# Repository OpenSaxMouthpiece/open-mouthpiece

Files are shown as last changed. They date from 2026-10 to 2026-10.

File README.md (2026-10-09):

<p>
  <picture>
    <source media="(prefers-color-scheme: dark)" srcset="docs/images/logo-dark.svg">
    
  </picture>
</p>

# Open Mouthpiece

**Design your own saxophone mouthpiece in the browser, then 3D-print it.**
Try it: **https://opensaxmouthpiece.org** · [User guide](docs/GUIDE.md)

> **This project is AI-generated.** The code, the mouthpiece generator, the presets and the
> documentation were written by Claude, Anthropic's AI model. A saxophonist directed it and prints
> and plays the results; see [How this was made](#how-this-was-made).

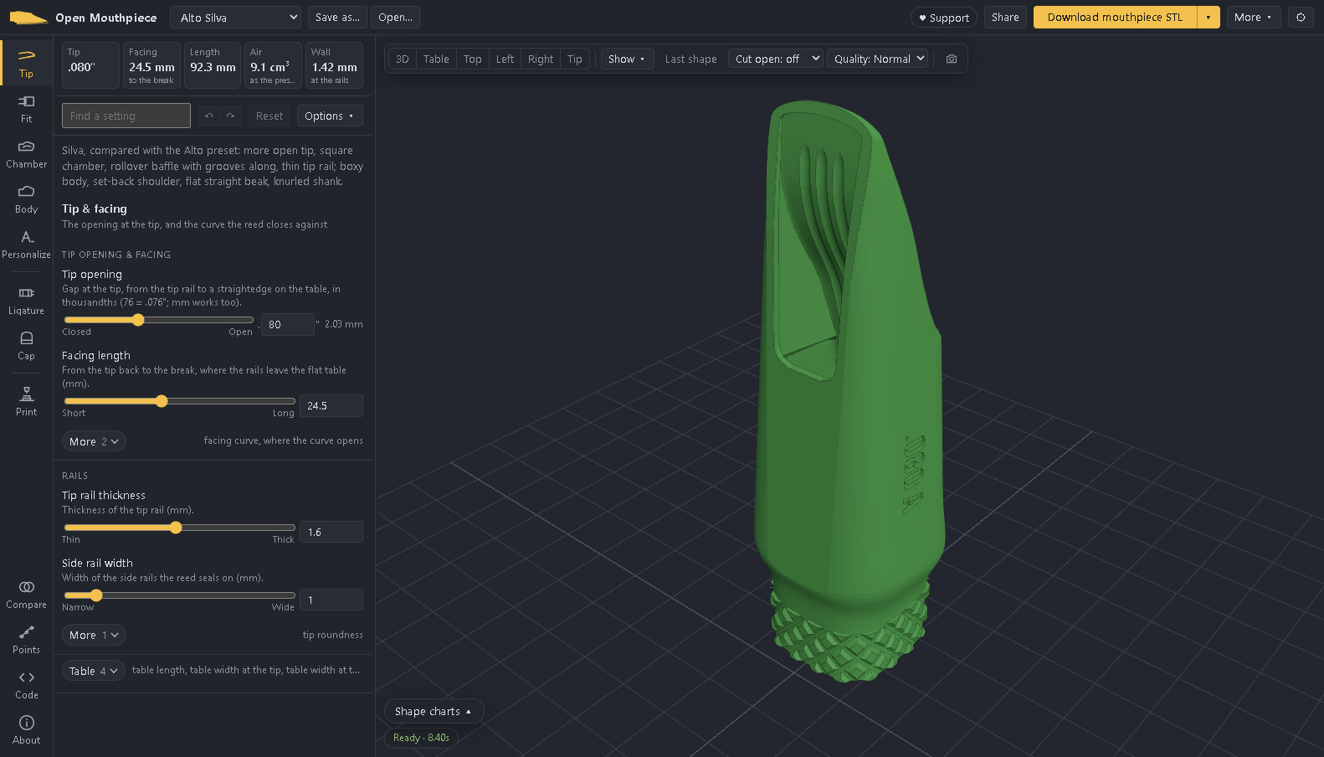
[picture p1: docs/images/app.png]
The app: the section buttons down the left, the readouts and the tip and facing settings, and a variant with lettering and a knurled shank in the 3D view


Change real design parameters (tip opening, facing, chamber, baffle, window, body and beak) and
download a printable STL. Everything runs in your browser: no account, nothing to install, and
nothing is saved on a server.

## What it does

- **Start from a preset**: soprano, alto, tenor or baritone, each with three variants (Flamma,
  Silva, Unda), plus a C-melody.
- **Shape it in sax terms**: tip opening in thousandths, facing length and curve (drag it, or pick
  one), chamber, baffle, window, body and beak. Every slider says what each end does.
- **Drag the shape itself**: the shape card over the view shows the facing, the outside and the
  inside from the side and in a slice across; **Edit shape** lets you pull their lines.
- **See the numbers**: tip, facing, length, inside air volume (and where that sits on the cork) and
  thinnest wall, and where feeler gauges stop along the facing.
- **Fit your horn**: set your neck cork's diameter and how tight it should be; print a small test
  ring first to check.
- **Make a matching ligature and cap**: a ring ligature and a cap built from the mouthpiece's own
  shape.
- **Compare A/B** with another design, with the original, or with an STL of a mouthpiece you have.
- **Personalize it**: text and pictures on the top, sides and shank, and rings, flutes, a spiral or
  knurling around the shank.
- **Keep and share**: save in your browser, download a .scad (it opens in OpenSCAD), the STL or a
  whole print kit, or send a link.
- Works on phones and tablets too.

The generator keeps every realistic combination printable: walls, the socket and the window are
limited so that no setting breaks the model.

| Shape charts | Compare A/B |
|---|---|
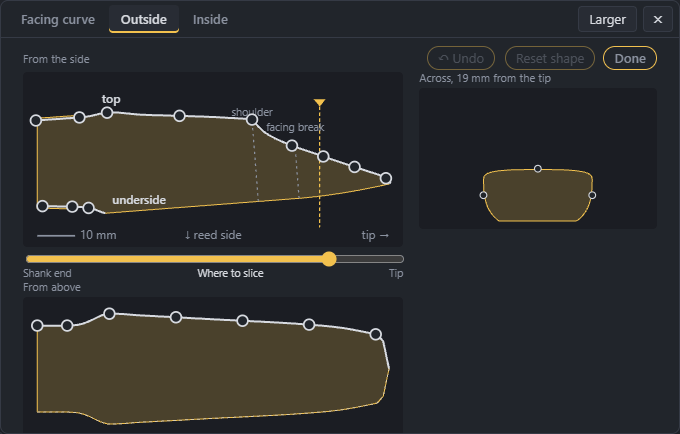
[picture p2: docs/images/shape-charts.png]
The outside chart in Edit shape: the side view with dots on the top and underside, a slice across it, and the view from above
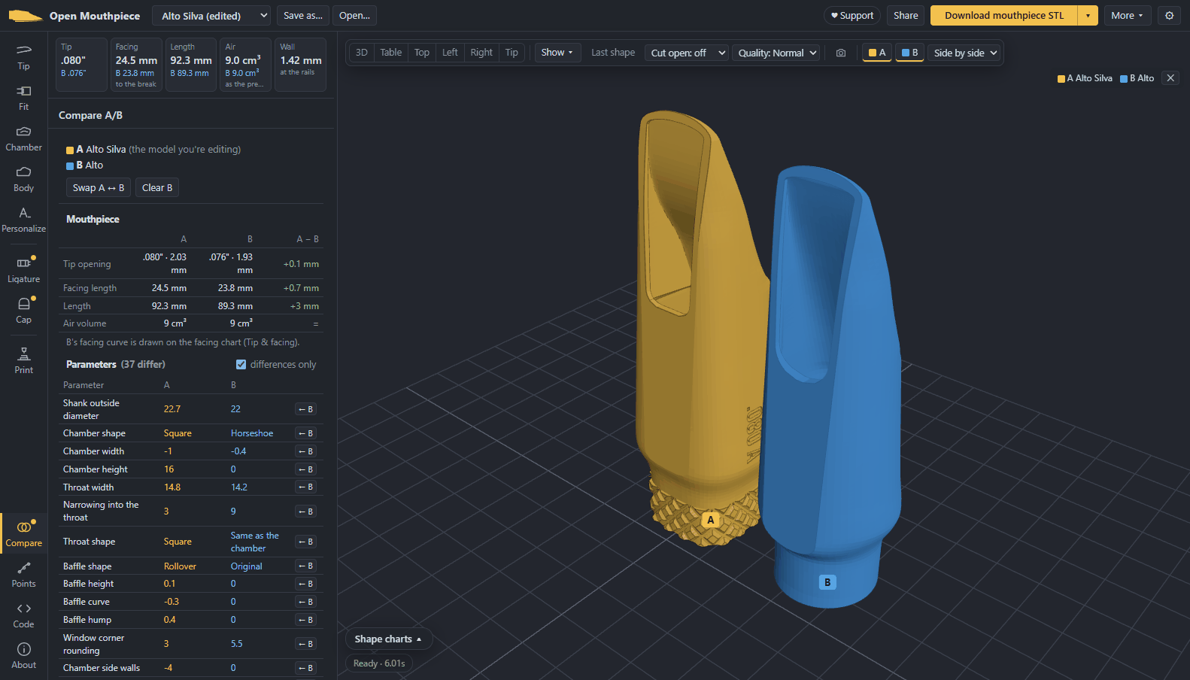
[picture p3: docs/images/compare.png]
A variant and the alto preset side by side, with the settings that differ
|  |  |
| **Ligature and cap** | **Phone** |
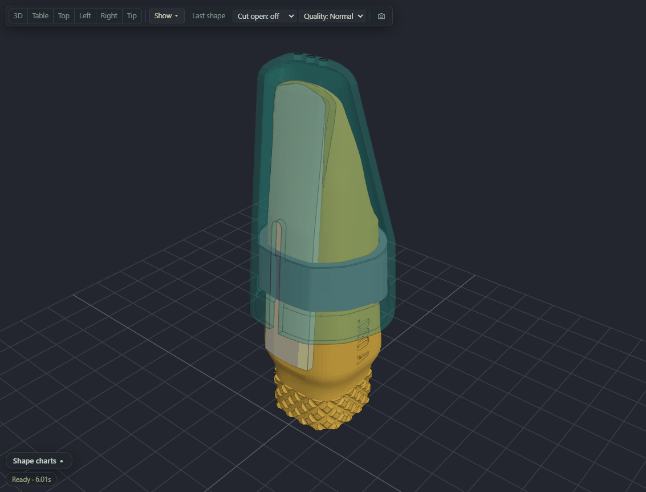
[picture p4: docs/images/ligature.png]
A mouthpiece with its reed, a printed ring ligature and a see-through cap
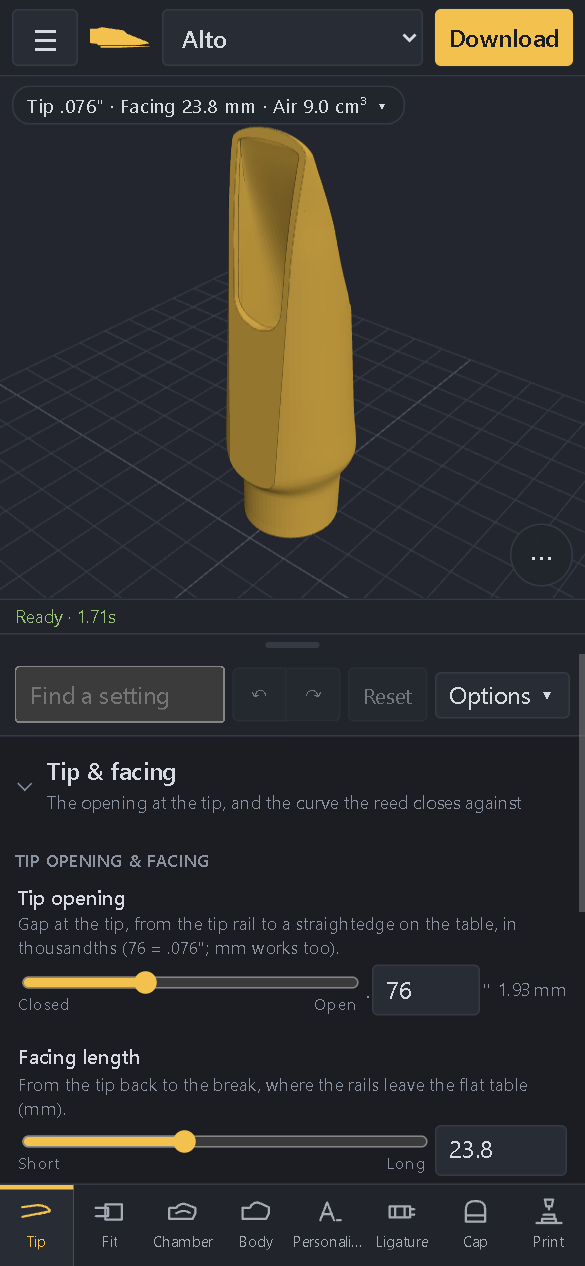
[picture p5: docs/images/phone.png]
The app on a phone: the view, the settings and the section bar along the bottom
|  |  |

## Status

Early but usable. The alto, tenor and baritone presets have been printed and played; the soprano,
the variants, the C-melody, the ligature and the cap haven't been printed yet.
[docs/PRINTING.md](docs/PRINTING.md) walks through printing, fitting and play-testing.
Feedback and prints are welcome (open an issue).

## Run it locally

The app needs only Node.js (OpenSCAD runs in the browser). The test scripts (`npm run check`,
`npm run sweep`) also need a recent OpenSCAD nightly (for the Manifold backend): set `OPENSCAD`
to its command-line program, or have `openscad` on the PATH.

```
npm install
npm run dev            # the app (OpenSCAD runs in the browser)
```

- **User guide**, from a first mouthpiece to every tool in the app: [docs/GUIDE.md](docs/GUIDE.md)
- The parts of a mouthpiece, and which settings change each: [docs/GLOSSARY.md](docs/GLOSSARY.md)
- Every setting, with pictures of what it changes: [docs/PARAMETERS.md](docs/PARAMETERS.md)
- Printing and play-testing: [docs/PRINTING.md](docs/PRINTING.md)
- Putting the app online: [docs/HOSTING.md](docs/HOSTING.md)
- Working on the code: [CONTRIBUTING.md](CONTRIBUTING.md)

The live site collects anonymous usage and error reports to improve the app: which designs and
settings get used, what gets printed (its numbers) and what fails. Never lettering, pictures or file
names, no cookies, no IP addresses, nothing that links one visit to the next; ⚙ "Share anonymous
usage" turns it off.

Open Mouthpiece is free, with no ads. If it made you a mouthpiece you like, you can
[support it on Ko-fi](https://ko-fi.com/opensaxmouthpiece).

## How this was made

Open Mouthpiece is AI-generated ("vibe coded"): the OpenSCAD generator, this web app, the
presets' measurements and the documentation were written by Claude, Anthropic's AI model, in
conversation with a saxophonist who set the direction, made the design calls, and prints and plays
the results. Read the code, and the numbers it gives you, with that in mind. The geometry is checked by automated
tests: every preset must come out as one closed, printable solid that matches its stored
reference, and a sweep tries over a thousand extreme and random settings to make sure they still
print. Printed alto, tenor and baritone pieces have been play-tested; reports from your own prints
are welcome.

## Credits

- **Anatomy and design parameters** follow M. Ozdemir et al., *Acta Acustica* 5, 46 (2021),
  open access under CC BY 4.0:
  https://acta-acustica.edpsciences.org/articles/aacus/abs/2021/01/aacus210019/aacus210019.html
- **Preset dimensions** were measured from Windy City Woodwinds' mouthpiece models on Thingiverse
  (CC BY-NC-SA): the "64" soprano (https://www.thingiverse.com/thing:6645219), "64" alto
  (https://www.thingiverse.com/thing:6645230), "64" tenor (https://www.thingiverse.com/thing:6645238) and
  "64" bari (https://www.thingiverse.com/thing:6645244). Their outlines were measured as coarse
  tables (a few to about 15 points per curve, smoothed by hand; the soprano's more finely) and
  rebuilt in this generator; no mesh from those models is included here. The ligature follows the
  idea of their printed friction-fit ligature. The site credits them too.
- **Fonts** in `scad/lib/fonts/` are under the SIL Open Font License (licence files alongside).
- **OpenSCAD** (GPL-2.0-or-later, source at https://github.com/openscad/openscad) does the
  geometry; the app runs its official WebAssembly build.

## License

Copyright (C) 2026 OpenSaxMouthpiece contributors.

This program is free software: you can redistribute it and/or modify it under the terms of the
GNU General Public License as published by the Free Software Foundation, either version 3 of the
License, or (at your option) any later version. See [LICENSE](LICENSE).

- **Your designs are yours.** The license covers this code, not the mouthpieces you design with it:
  the STLs you export and the objects you print from them are yours to use, share or sell. (A
  full .scad download contains the generator's code, so sharing that file shares GPL code.)
- **Name:** "Open Mouthpiece" and opensaxmouthpiece.org are not licensed under the GPL; a fork
  is welcome, under its own name.
- Third-party parts keep their own licenses (see Credits).

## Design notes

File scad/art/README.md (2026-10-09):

# Pictures for `top_image`

SVG drawings the generator can engrave (or raise) on the mouthpiece, the ligature or the cap. Pick one in the
app (Personalize → Picture on top), or upload your own there.

Examples (original drawings, same license as the project):

| File | Suggested `top_image_width` |
|---|---|
| `saxophone.svg` | 16 mm or more |
| `happy_face.svg` | 10 mm or more |
| `sample_note.svg` | 10 mm or more |
| `treble_clef.svg` | 8 mm or more |
| `beamed_notes.svg` | 10 mm or more |
| `star.svg` | 8 mm or more |
| `heart.svg` | 8 mm or more |
| `flame.svg` | 10 mm or more |
| `skull.svg` | 10 mm or more |
| `cat.svg` | 10 mm or more |
| `bird.svg` | 12 mm or more |
| `wave.svg` | 12 mm or more |
| `lightning.svg` | 8 mm or more |
| `ash_leaf.svg` | 10 mm or more |
| `birch_leaf.svg` | 8 mm or more |
| `cedar_tree.svg` | 8 mm or more |
| `element_fire.svg`, `element_leaf.svg`, `element_water.svg` (a set) | 10 mm or more |

## Making your own

- **Use filled shapes.** OpenSCAD reads fills; outlines (strokes) come out filled in or broken.
  In Inkscape: select all, Path → Stroke to Path.
- **Holes go inside the shape's own path** (a subpath with `fill-rule="evenodd"`, or drawn the
  opposite way round). A white shape drawn on top does nothing: colours are ignored.
- **Keep lines printable:** about 0.5 mm or wider at the width you engrave it (a line that is 3% of
  the drawing's width is 0.5 mm at 16 mm).
- Photos and PNGs need tracing to an outline first (Inkscape: Path → Trace Bitmap).
- Only use logos and artwork you have the right to use.

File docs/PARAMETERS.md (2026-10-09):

# Parameters

Every setting of the generator, as OpenSCAD's Customizer shows them. The app shows each one in a
section of its settings panel (the main ones first, the rest under the section's More), under
friendlier names; the name in brackets is the one in the `.scad` file. Lengths are in mm, angles in degrees.

Each picture is the alto preset at two values of one setting, the rest unchanged, seen where the
setting acts (a section when it acts inside):

- **gray**: in both
- **blue**: added going from the first value to the second
- **orange**: taken away going from the first value to the second

This page is made by `node scripts/param_docs.mjs` from `scad/lib/mouthpiece_base.scad`.

Sections: [Shank](#shank) · [Chamber](#chamber) · [Baffle](#baffle) · [Window](#window) · [Table](#table) · [Facing](#facing) · [Exterior](#exterior) · [Lettering](#lettering) · [Profile overrides](#profile-overrides) · [Manufacturing](#manufacturing) · [Ligature](#ligature) · [Cap](#cap) · [Output](#output)

## Shank

### Neck cork diameter (`neck_cork_diameter`)

Your neck cork's diameter (mm), measured with calipers.

Range: 10 to 27, step 0.05.

Presets: Alto `16.2` · Tenor `17.2` · Bari `18.0` · Soprano `13.8`.

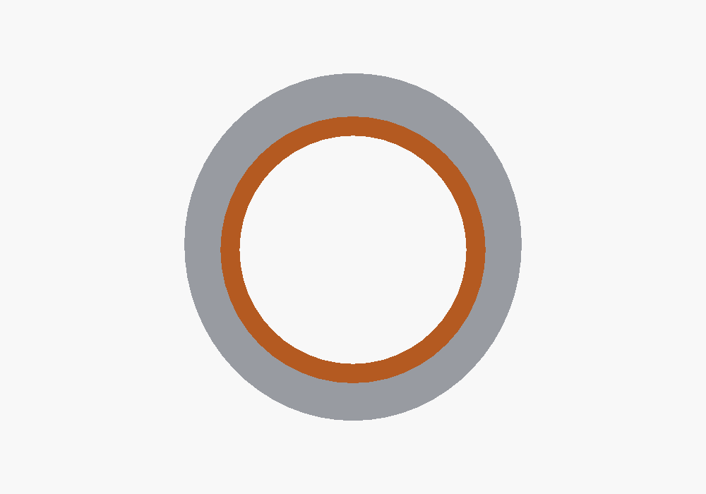
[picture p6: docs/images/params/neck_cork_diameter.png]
neck_cork_diameter: 15 → 17.5


*15 → 17.5*

### Cork squeeze (`shank_clearance`)

How much smaller than your cork the socket is (mm): bigger = tighter. Try 0.1-0.3.

Range: 0 to 0.6, step 0.01.

Presets: Alto `0.2` · Tenor `0.2` · Bari `0.2` · Soprano `0.2`.

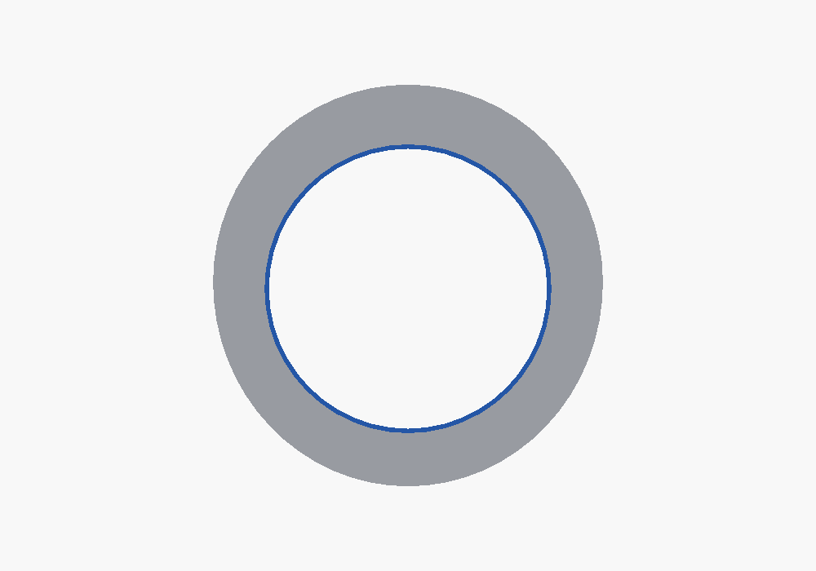
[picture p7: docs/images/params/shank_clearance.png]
shank_clearance: 0 → 0.5


*0 → 0.5*

### Lead-in at the opening (`shank_bevel`)

How much wider the socket's mouth is, per side (mm), to ease it onto the cork.

Range: 0 to 3, step 0.1.

Presets: Alto `1.0` · Tenor `1.0` · Bari `1.0` · Soprano `1.0`.

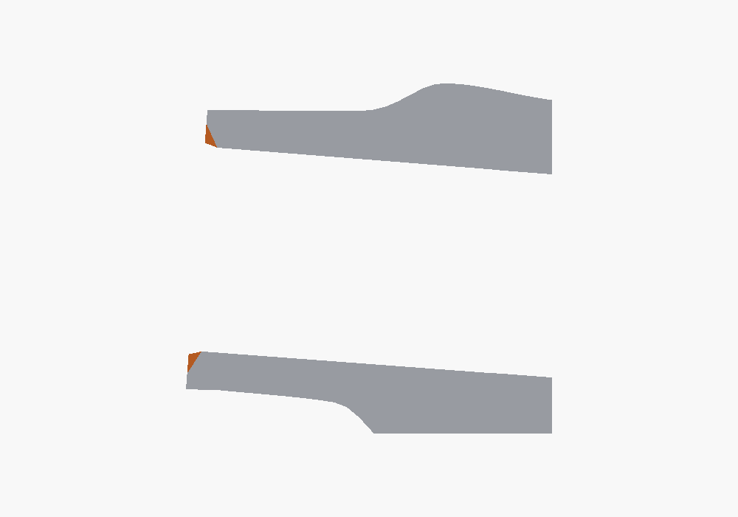
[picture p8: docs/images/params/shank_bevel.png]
shank_bevel: 0.3 → 1.8


*0.3 → 1.8*

### Lead-in length (`shank_bevel_depth`)

How far in the socket's lead-in goes (mm).

Range: 0.2 to 20, step 0.1.

Presets: Alto `1.0` · Tenor `1.0` · Bari `1.0` · Soprano `1.0`.

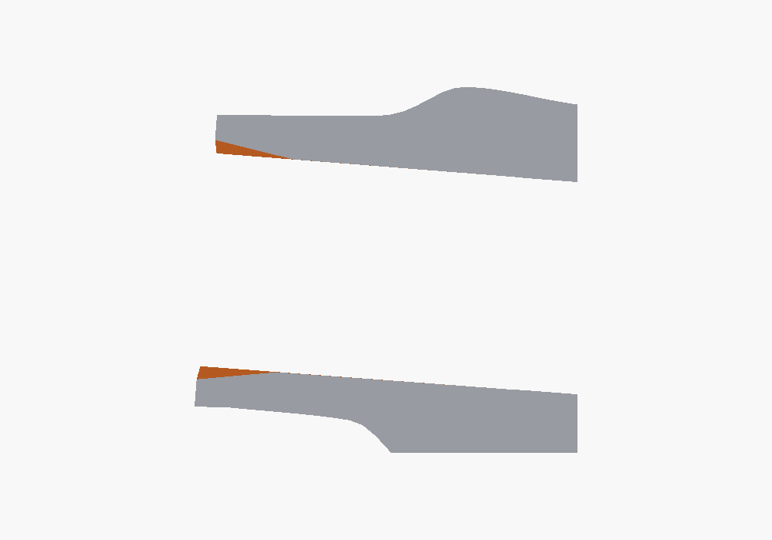
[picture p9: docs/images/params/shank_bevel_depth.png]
shank_bevel_depth: 0.2 → 6


*0.2 → 6*

### How far the cork goes in (`shank_depth`)

How far the cork goes in (mm). Other settings give way to keep it.

Range: 10 to 70, step 0.5.

Presets: Alto `22.0` · Tenor `26.0` · Bari `30.0` · Soprano `25.5`.

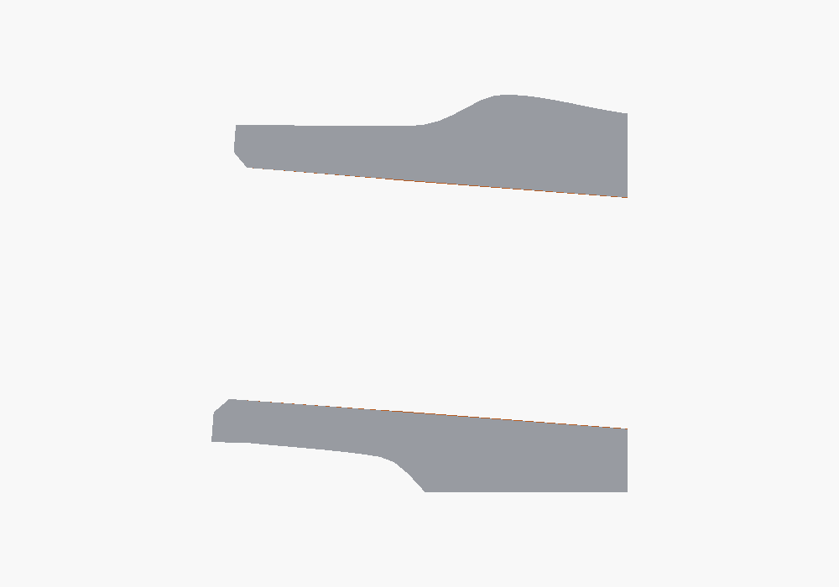
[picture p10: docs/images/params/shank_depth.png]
shank_depth: 10 → 37


*10 → 37*

### Bore (behind the cork) (`bore_diameter`)

Diameter of the tube behind the socket (mm), about your neck tip's inside diameter.

Range: 8 to 24, step 0.1.

Presets: Alto `16.0` · Tenor `17.0` · Bari `16.9` · Soprano `13.6`.

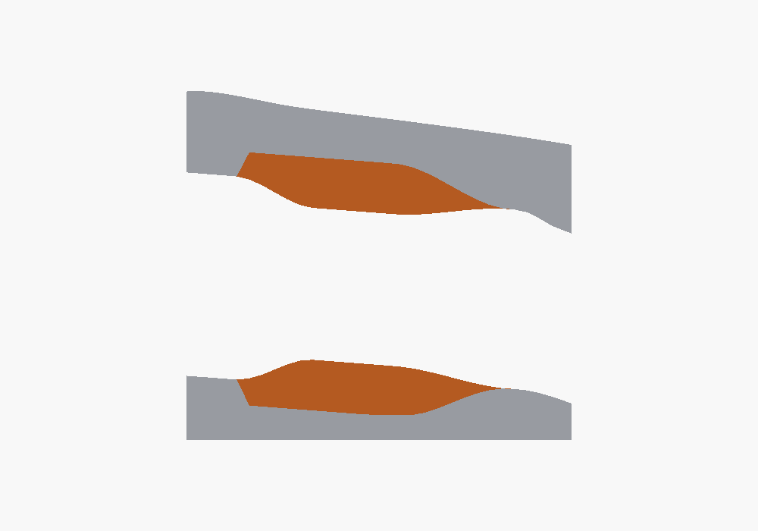
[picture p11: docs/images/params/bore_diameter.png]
bore_diameter: 12 → 20


*12 → 20*

### Table angle to the neck (`bore_tilt`)

Angle between the neck's line and the reed table (degrees); about 4 is typical.

Range: -3 to 8, step 0.1.

Presets: Alto `4.4` · Tenor `4.1` · Bari `4.8` · Soprano `4.1`.

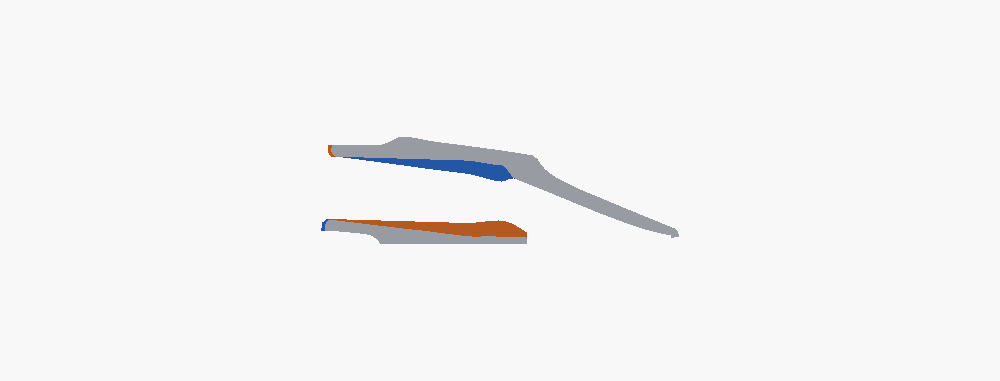
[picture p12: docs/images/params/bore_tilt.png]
bore_tilt: 1.7 → 7.2


*1.7 → 7.2*

### Shank outside diameter (`shank_diameter`)

Outside diameter of the shank at the neck end (mm); grows if the wall gets too thin.

Range: 14 to 32, step 0.1.

Presets: Alto `22` · Tenor `23` · Bari `24.1` · Soprano `17.8`.

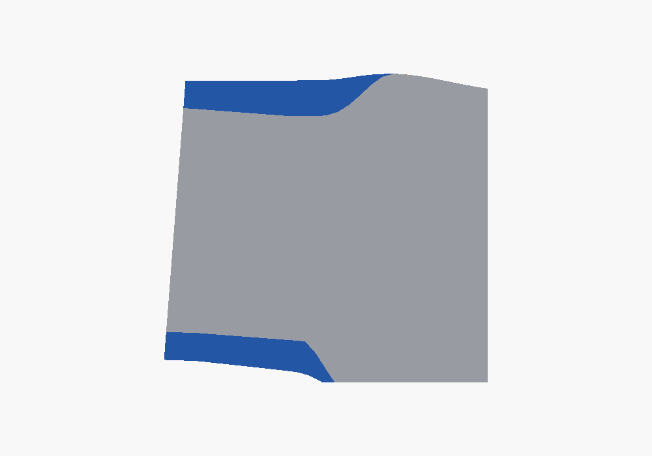
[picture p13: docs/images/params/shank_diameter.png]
shank_diameter: 19 → 25


*19 → 25*

## Chamber

### Chamber shape (`chamber_shape`)

Cross-section of the chamber after the throat.

Range: `round`, `square`, `horseshoe`.

Presets: Alto `horseshoe` · Tenor `round` · Bari `round` · Soprano `square`.

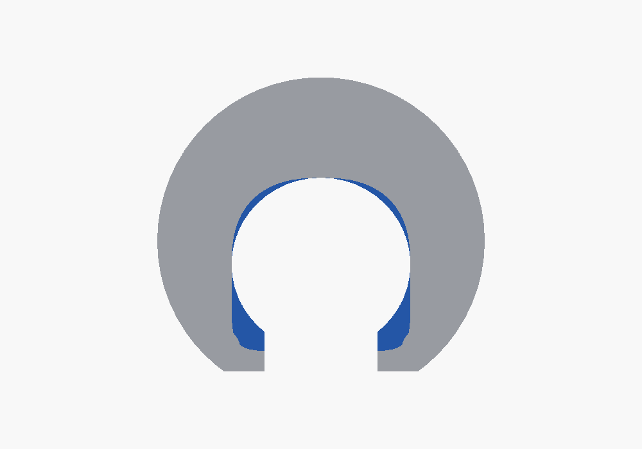
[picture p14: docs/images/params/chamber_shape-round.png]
chamber_shape: horseshoe (the alto's) → round


*`horseshoe` (the alto's) → `round`*

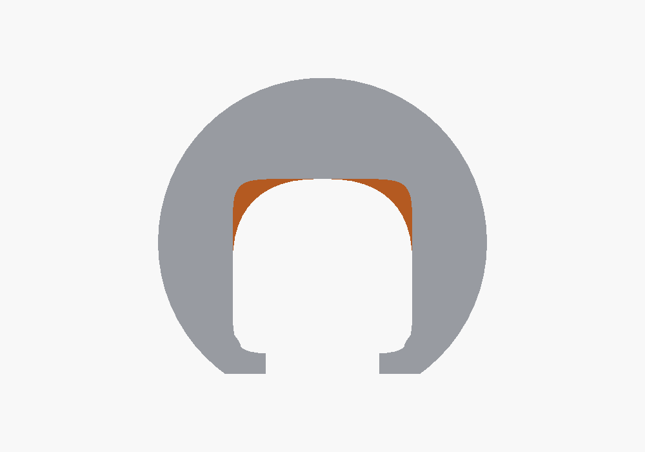
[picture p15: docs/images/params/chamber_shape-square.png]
chamber_shape: horseshoe (the alto's) → square


*`horseshoe` (the alto's) → `square`*

### Chamber width (`chamber_width`)

Width of the chamber after the throat (mm), whatever the throat's width.

Range: 4 to 36, step 0.1.

Presets: Alto `13.8` · Tenor `14.5` · Bari `15.4` · Soprano `9.5`.

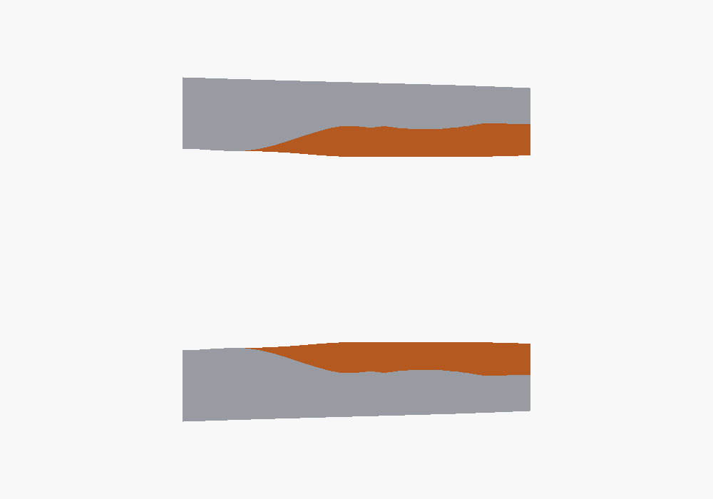
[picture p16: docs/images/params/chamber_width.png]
chamber_width: 13.2 → 18


*13.2 → 18*

### Widening after the throat (`chamber_flare`)

How gradually the chamber widens after the throat: low = quickly, high = slowly.

Range: 0.1 to 0.9, step 0.05.

Presets: Alto `0.4` · Tenor `0.4` · Bari `0.4` · Soprano `0.4`.

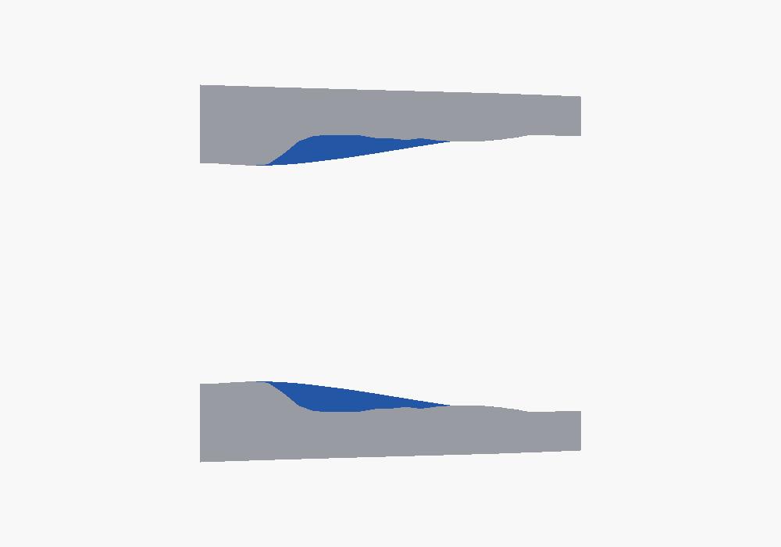
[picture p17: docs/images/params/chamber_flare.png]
chamber_flare: 0.15 → 0.8


*0.15 → 0.8*

### How far the full width runs (`chamber_full_length`)

How far the full width runs toward the tip (mm); 40 = as far as it can.

Range: 0 to 40, step 0.5.

Presets: Alto `40` · Tenor `40` · Bari `40` · Soprano `40`.

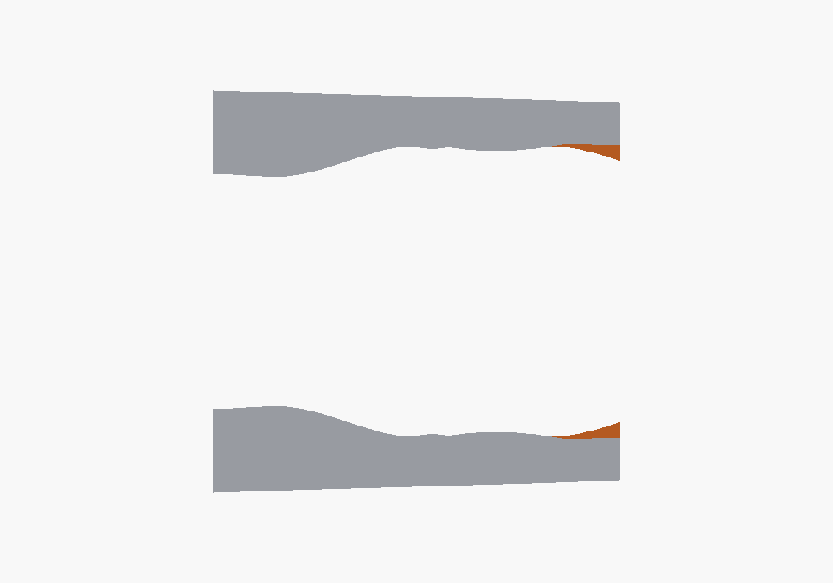
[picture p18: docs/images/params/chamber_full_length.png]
chamber_full_length: 5 → 40


*5 → 40*

### Chamber height (`chamber_height`)

Chamber height before the window (mm); 0 = round. More lowers the floor, less raises it.

Range: 0 to 30, step 0.1.

Presets: Alto `0` · Tenor `0` · Bari `0` · Soprano `0`.

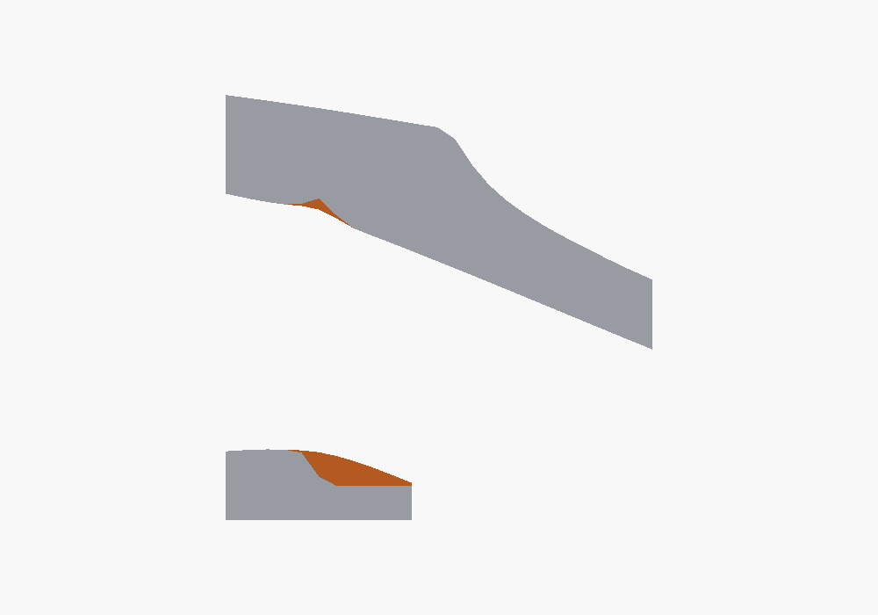
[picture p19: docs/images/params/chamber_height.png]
chamber_height: 0 → 18


*0 → 18*

### Chamber floor (`floor_shape`)

Floor from throat to window: - drops early (deeper), + stays high (a ramp).

Range: -1 to 1, step 0.05.

Presets: Alto `0` · Tenor `0` · Bari `0` · Soprano `0`.

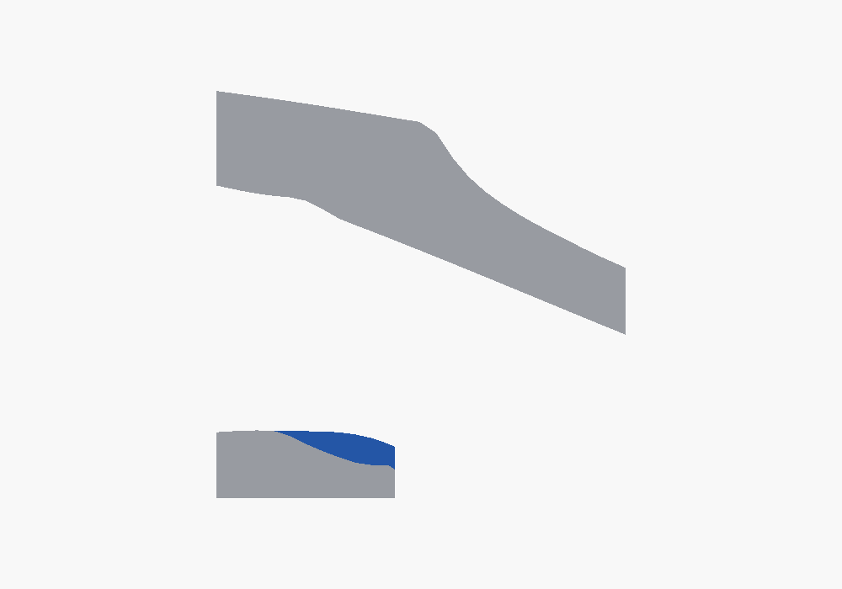
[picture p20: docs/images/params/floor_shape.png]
floor_shape: -0.8 → 0.8


*-0.8 → 0.8*

### Throat position (`throat_position`)

Where the throat (the narrowest point inside) sits, from the neck end (mm).

Range: 20 to 90, step 0.5.

Presets: Alto `43.5` · Tenor `53.0` · Bari `86.5` · Soprano `34.5`.

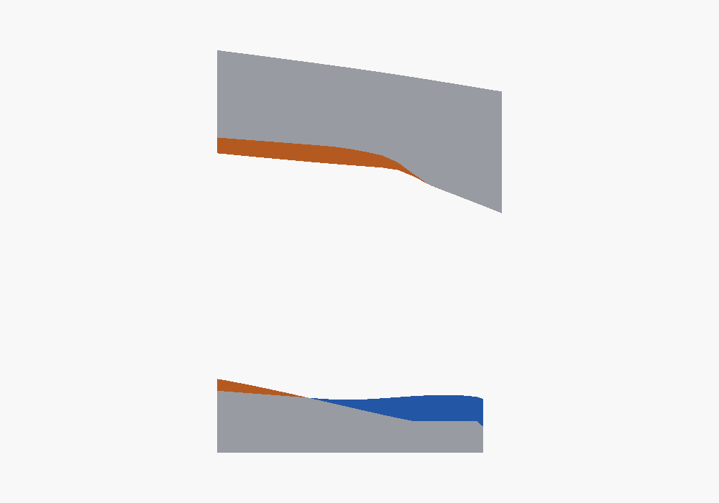
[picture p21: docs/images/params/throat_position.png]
throat_position: 26 → 61


*26 → 61*

### Throat width (`throat_width`)

Width of the throat, the narrowest point inside (mm).

Range: 5 to 24, step 0.1.

Presets: Alto `14.2` · Tenor `14.9` · Bari `14.8` · Soprano `9.3`.

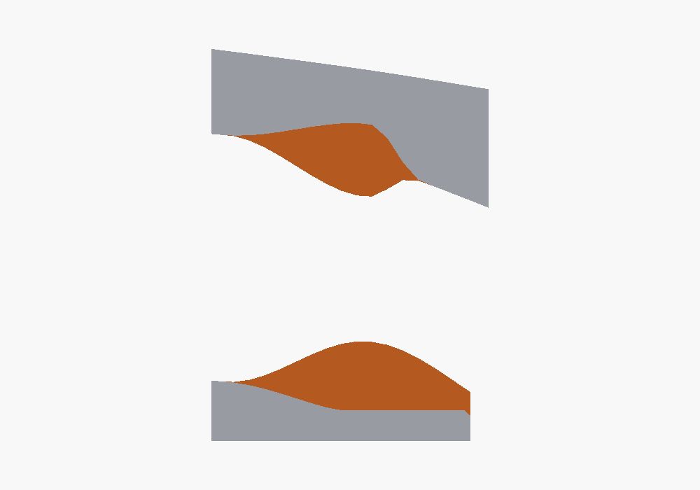
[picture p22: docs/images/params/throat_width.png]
throat_width: 9.4 → 18.9


*9.4 → 18.9*

### Narrowing into the throat (`throat_taper`)

Length of the bore's narrowing into the throat (mm). Short = an abrupt step.

Range: 1 to 80, step 0.5.

Presets: Alto `9` · Tenor `11` · Bari `55` · Soprano `3`.

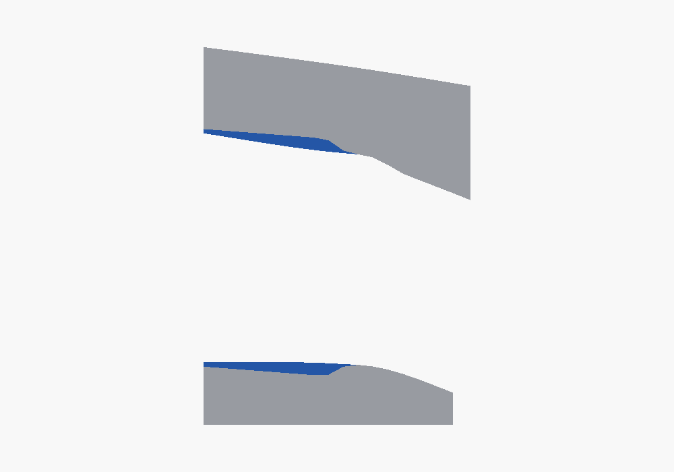
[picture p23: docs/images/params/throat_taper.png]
throat_taper: 2 → 16


*2 → 16*

### Throat shape (`throat_shape`)

Throat cross-section; "chamber" = the same as the chamber.

Range: `chamber`, `round`, `square`, `horseshoe`.

Presets: Alto `chamber` · Tenor `chamber` · Bari `chamber` · Soprano `chamber`.

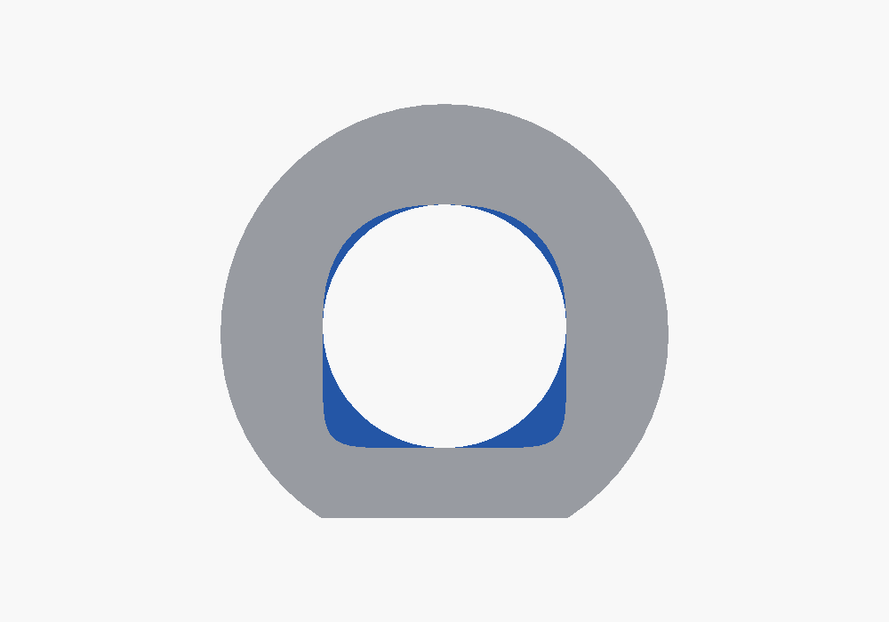
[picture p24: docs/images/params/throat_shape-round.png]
throat_shape: chamber (the alto's) → round


*`chamber` (the alto's) → `round`*

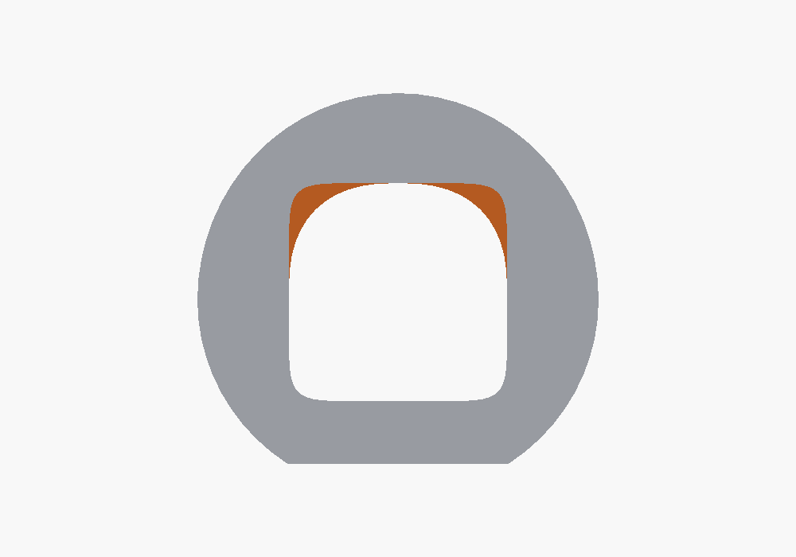
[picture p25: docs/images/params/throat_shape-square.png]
throat_shape: chamber (the alto's) → square


*`chamber` (the alto's) → `square`*

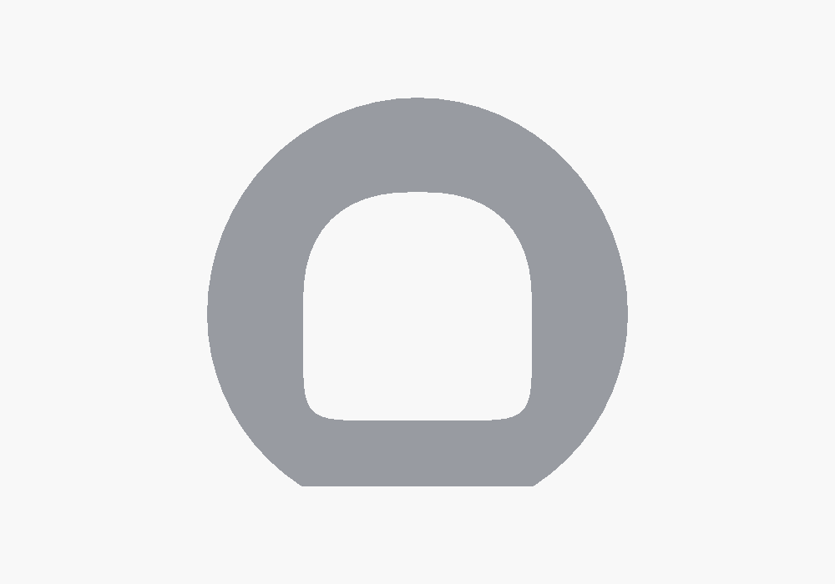
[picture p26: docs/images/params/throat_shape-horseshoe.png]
throat_shape: chamber (the alto's) → horseshoe


*`chamber` (the alto's) → `horseshoe`*

## Baffle

### Baffle shape (`baffle_type`)

The roof's shape over the reed (see the picture); Original = the preset's own.

Range: `measured`, `flat`, `rollover`, `step`, `concave`.

Presets: Alto `measured` · Tenor `measured` · Bari `measured` · Soprano `measured`.

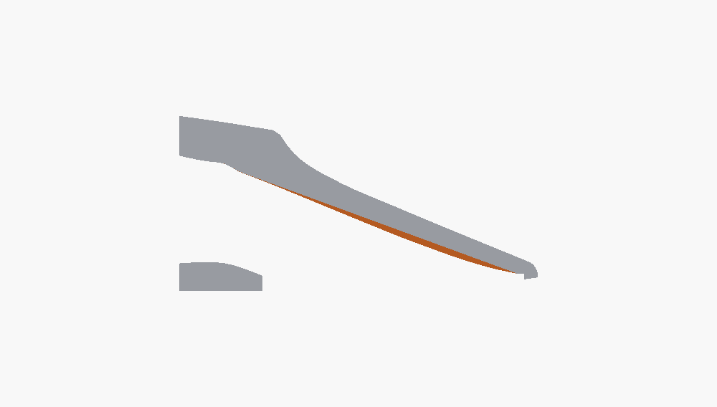
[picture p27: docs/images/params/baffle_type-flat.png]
baffle_type: measured (the alto's) → flat


*`measured` (the alto's) → `flat`*

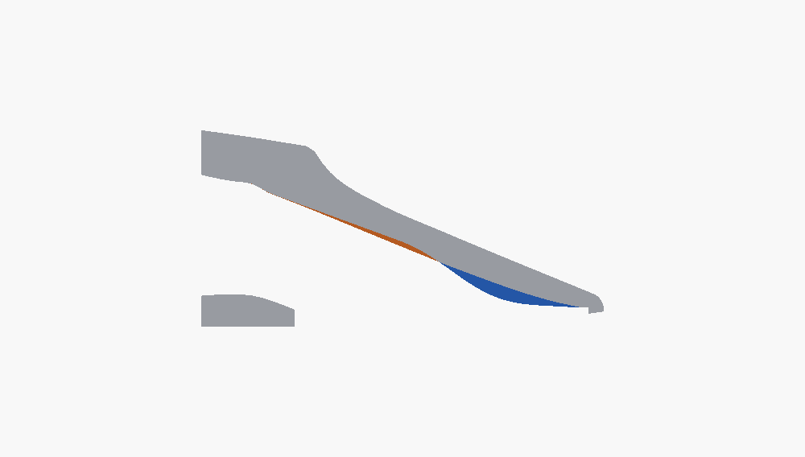
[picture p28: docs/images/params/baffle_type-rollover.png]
baffle_type: measured (the alto's) → rollover


*`measured` (the alto's) → `rollover`*

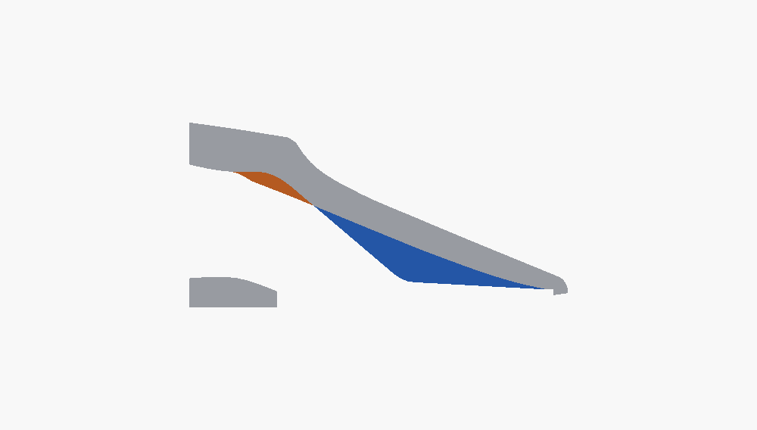
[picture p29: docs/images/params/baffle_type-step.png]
baffle_type: measured (the alto's) → step


*`measured` (the alto's) → `step`*

baffle_type: measured (the alto's) → concave

*`measured` (the alto's) → `concave`*

### Baffle height (`baffle_height`)

Moves the baffle toward the reed (+) or away from it (-) (mm).

Range: -3 to 4, step 0.1.

Presets: Alto `0` · Tenor `0` · Bari `0` · Soprano `0`.

baffle_height: -1 → 1.5

*-1 → 1.5*

### Where the baffle begins (`baffle_start`)

Moves where the baffle begins, toward the tip (+) or the neck (-) (mm).

Range: -15 to 15, step 0.5.

Presets: Alto `0` · Tenor `0` · Bari `0` · Soprano `0`.

baffle_start: -6 → 6

*-6 → 6*

### Baffle curve (`baffle_curve`)

Bends the baffle: - comes down early, + stays up and drops late.

Range: -1 to 1, step 0.05.

Presets: Alto `0` · Tenor `0` · Bari `0` · Soprano `0`.

baffle_curve: -0.6 → 0.6

*-0.6 → 0.6*

### Baffle hump (`baffle_hump`)

Height of a smooth hump on the baffle just behind the tip (mm).

Range: 0 to 3, step 0.1.

Presets: Alto `0` · Tenor `0` · Bari `0` · Soprano `0`.

baffle_hump: 0 → 1.5

*0 → 1.5*

### Baffle texture (`baffle_texture`)

A texture on the baffle: grooves along it, grooves across it, or dimples.

Range: `none`, `along`, `across`, `dimples`.

Presets: Alto `none` · Tenor `none` · Bari `none` · Soprano `none`.

### Texture style (`baffle_texture_style`)

Texture cut into the baffle (engraved) or standing out of it (raised).

Range: `engraved`, `raised`.

Presets: Alto `engraved` · Tenor `engraved` · Bari `engraved` · Soprano `engraved`.

### Texture depth (`baffle_texture_depth`)

How deep the texture cuts, or how far it stands out (mm); less where there is no room.

Range: 0.1 to 1, step 0.05.

Presets: Alto `0.4` · Tenor `0.4` · Bari `0.4` · Soprano `0.4`.

### Texture spacing (`baffle_texture_spacing`)

Distance between the grooves or dimples (mm).

Range: 1.5 to 8, step 0.1.

Presets: Alto `3` · Tenor `3` · Bari `3` · Soprano `3`.

## Window

### Window length (`window_length`)

Length of the opening under the reed (mm).

Range: 8 to 70, step 0.5.

Presets: Alto `39.0` · Tenor `42.0` · Bari `54.3` · Soprano `28.3`.

window_length: 23.5 → 54.5

*23.5 → 54.5*

### Window width (`window_width`)

Width of the opening under the reed (mm); kept inside the rails automatically.

Range: 6 to 22, step 0.1.

Presets: Alto `15.1` · Tenor `16.2` · Bari `17.2` · Soprano `12.5`.

window_width: 11.1 → 19.1

*11.1 → 19.1*

### Window narrows at the back (`window_taper`)

How much narrower the window is at the back (mm).

Range: 0 to 12, step 0.1.

Presets: Alto `3.3` · Tenor `4.3` · Bari `4.3` · Soprano `2.7`.

window_taper: 0.3 → 6.3

*0.3 → 6.3*

### Window corner rounding (`window_rear_radius`)

Rounding of the window's back corners (mm).

Range: 0 to 10, step 0.1.

Presets: Alto `5.5` · Tenor `5.3` · Bari `6.3` · Soprano `4.8`.

window_rear_radius: 1 → 8

*1 → 8*

### Chamber side walls (`sidewall_angle`)

Chamber side walls over the window (degrees): + lean out (scooped), - lean in.

Range: -20 to 30, step 1.

Presets: Alto `0` · Tenor `0` · Bari `0` · Soprano `0`.

sidewall_angle: -10 → 15

*-10 → 15*

### Side rail width (`side_rail_width`)

Width of the side rails the reed seals on (mm).

Range: 0.8 to 2.5, step 0.05.

Presets: Alto `1.0` · Tenor `1.0` · Bari `1.0` · Soprano `1.0`.

side_rail_width: 0.8 → 1.8

*0.8 → 1.8*

### Tip rail thickness (`tip_rail_thickness`)

Thickness of the tip rail (mm).

Range: 0.3 to 3, step 0.02.

Presets: Alto `2.0` · Tenor `1.4` · Bari `1.8` · Soprano `1.76`.

tip_rail_thickness: 1 → 3

*1 → 3*

### Tip roundness (`tip_curve`)

How round the tip is, seen from above: how far back its curve reaches (mm).

Range: 0.5 to 12, step 0.1.

Presets: Alto `3.5` · Tenor `3.8` · Bari `4.3` · Soprano `3.5`.

tip_curve: 2 → 6

*2 → 6*

## Table

### Table width at the tip (`table_width_tip`)

Width of the reed seat at the tip (mm). Match your reed.

Range: 8 to 30, step 0.1.

Presets: Alto `16.8` · Tenor `17.6` · Bari `19.5` · Soprano `14.9`.

table_width_tip: 11.3 → 22.3

*11.3 → 22.3*

### Table width at the back (`table_width_rear`)

Width of the reed seat at the back (mm). Match your reed's heel.

Range: 8 to 30, step 0.1.

Presets: Alto `13.2` · Tenor `14.7` · Bari `13.9` · Soprano `11.3`.

table_width_rear: 8 → 18.7

*8 → 18.7*

### Table length (`table_length`)

From the tip to the table's back end (mm), facing included; longer than the reed is normal.

Range: 50 to 120, step 0.5.

Presets: Alto `71.8` · Tenor `77.7` · Bari `101.5` · Soprano `55.44`.

table_length: 66 → 76

*66 → 76*

### Table hollow (`table_concavity`)

A slight hollow along the reed seat (mm) so the reed seals at both ends.

Range: 0 to 0.1, step 0.005.

Presets: Alto `0` · Tenor `0` · Bari `0` · Soprano `0`.

## Facing

### Tip opening (`tip_opening`)

Gap at the tip, from the tip rail to a straightedge on the table (mm).

Range: 0.5 to 4.5, step 0.01.

Presets: Alto `1.93` · Tenor `2.41` · Bari `2.79` · Soprano `1.65`.

tip_opening: 1.5 → 2.6 (heights stretched 6x)

*1.5 → 2.6 (heights stretched 6x)*

### Facing length (`facing_length`)

From the tip back to the break, where the rails leave the flat table (mm).

Range: 10 to 45, step 0.1.

Presets: Alto `23.8` · Tenor `25.2` · Bari `28.0` · Soprano `20.0`.

facing_length: 20 → 28 (heights stretched 6x)

*20 → 28 (heights stretched 6x)*

### Facing curve (`facing_model`)

How the facing curves (the chart's buttons set it too): Power curve, Radius or Gauge points.

Range: `power`, `arc`, `gauge`.

Presets: Alto `power` · Tenor `power` · Bari `power` · Soprano `power`.

facing_model: power (the alto's) → arc (heights stretched 6x)

*`power` (the alto's) → `arc` (heights stretched 6x)*

### Where the curve opens (`facing_exponent`)

For the Power curve: 2 opens evenly; lower opens sooner, higher later.

Range: 1.5 to 3, step 0.05.

Presets: Alto `1.8` · Tenor `1.8` · Bari `1.8` · Soprano `1.8`.

facing_exponent: 1.5 → 3 (heights stretched 6x)

*1.5 → 3 (heights stretched 6x)*

## Exterior

### Length (`overall_length`)

Total length, neck end to tip (mm). Also changes the inside volume.

Range: 55 to 160, step 0.1.

Presets: Alto `89.3` · Tenor `96.7` · Bari `142.0` · Soprano `66.0`.

overall_length: 82 → 96

*82 → 96*

### Body width (`body_width`)

Widest outside width of the body, side to side (mm).

Range: 18 to 40, step 0.1.

Presets: Alto `29` · Tenor `30.7` · Bari `31.7` · Soprano `23.6`.

body_width: 26 → 32

*26 → 32*

### Body height (`body_height`)

Height of the body's top above the reed table, at its tallest (mm).

Range: 18 to 40, step 0.1.

Presets: Alto `27.6` · Tenor `29.3` · Bari `30.5` · Soprano `22.5`.

body_height: 25 → 30

*25 → 30*

### Beak height at the tip (`beak_tip_height`)

Height of the beak at the tip (mm).

Range: 2 to 8, step 0.1.

Presets: Alto `3.6` · Tenor `3.6` · Bari `4.8` · Soprano `3.0`.

beak_tip_height: 2.8 → 5

*2.8 → 5*

### Body cross-section (`body_squareness`)

Body cross-section: 2 = round, higher = boxier, lower = pointed sides.

Range: 1.2 to 8, step 0.1.

Presets: Alto `2.0` · Tenor `2.0` · Bari `2.0` · Soprano `2.0`.

body_squareness: 1.5 → 4

*1.5 → 4*

### Beak top (`beak_squareness`)

The beak's top, seen from the tip: ridged (a peak along it) or flat.

Range: 1.2 to 8, step 0.1.

Presets: Alto `1.6` · Tenor `1.5` · Bari `1.4` · Soprano `1.5`.

beak_squareness: 1.2 → 4

*1.2 → 4*

### Beak curve (`beak_curve`)

The beak's line from the side: full (bulging) or scooped (hollowed).

Range: -1 to 1, step 0.05.

Presets: Alto `0` · Tenor `0` · Bari `0` · Soprano `0`.

beak_curve: -0.8 → 0.8

*-0.8 → 0.8*

### Beak length (`beak_length`)

Moves the shoulder (the chart's shoulder dot) back for a longer beak, forward for shorter (mm).

Range: -15 to 15, step 0.5.

Presets: Alto `0` · Tenor `0` · Bari `0` · Soprano `0`.

beak_length: -8 → 8

*-8 → 8*

### Shoulder smoothness (`shoulder_smoothness`)

0 = a crisp step (as designed), 1 = a smooth, gradual drop into the beak.

Range: 0 to 1, step 0.05.

Presets: Alto `0` · Tenor `0` · Bari `0` · Soprano `0`.

shoulder_smoothness: 0 → 1

*0 → 1*

### Beak top width (`beak_top_width`)

How wide the beak's top is: - narrower, rounder top; + wider, fuller top. 0 = as designed.

Range: -1 to 1, step 0.05.

Presets: Alto `0` · Tenor `0` · Bari `0` · Soprano `0`.

beak_top_width: -1 → 1

*-1 → 1*

### Shoulder sweep (`shoulder_sweep`)

How far the shoulder line runs down the sides toward the tip (mm); 0 = straight across.

Range: 0 to 20, step 0.5.

Presets: Alto `0` · Tenor `0` · Bari `0` · Soprano `0`.

shoulder_sweep: 0 → 12

*0 → 12*

### Sides near the table (`underside_squareness`)

The lower sides near the tip, seen from the tip: tucked in (curved) or straight down.

Range: 1.2 to 8, step 0.1.

Presets: Alto `1.2` · Tenor `1.2` · Bari `1.2` · Soprano `1.2`.

underside_squareness: 1.2 → 4

*1.2 → 4*

## Lettering

Text and pictures on the outside. The app's **Personalize** section has the main ones.

### Text on top (`top_text`)

Text on top (empty = none), several lines OK; {tip} puts in the tip size.

Range: text.

Presets: Alto `(empty)` · Tenor `(empty)` · Bari `(empty)` · Soprano `(empty)`.

### Text size (`top_text_size`)

Letter height (mm).

Range: 2 to 20, step 0.5.

Presets: Alto `5` · Tenor `5` · Bari `5` · Soprano `5`.

### Text direction (`top_text_angle`)

Which way the text reads: along the mouthpiece or across it (flipped = upside down).

Range: 0 to 270, step 90.

Presets: Alto `90` · Tenor `90` · Bari `90` · Soprano `90`.

### Text position (`top_text_position`)

Moves the top text toward the tip (+) or the shank (-) (mm).

Range: -50 to 50, step 0.5.

Presets: Alto `0` · Tenor `0` · Bari `0` · Soprano `0`.

### Picture on top (`top_image`)

A picture (SVG file) on top; solid shapes work, thin line drawings don't.

Range: text.

Presets: Alto `(empty)` · Tenor `(empty)` · Bari `(empty)` · Soprano `(empty)`.

### Picture size (`top_image_width`)

Picture width (mm).

Range: 4 to 90, step 0.5.

Presets: Alto `14` · Tenor `14` · Bari `14` · Soprano `14`.

### Picture height / width (`top_image_aspect`)

Picture height / width, for spacing (the app fills it in).

Range: 0.1 to 10, step 0.01.

Presets: Alto `1` · Tenor `1` · Bari `1` · Soprano `1`.

### Picture rotation (`top_image_angle`)

Picture rotation (degrees).

Range: 0 to 345, step 15.

Presets: Alto `0` · Tenor `0` · Bari `0` · Soprano `0`.

### Picture position (`top_image_position`)

Moves the picture toward the tip (+) or the shank (-) (mm).

Range: -50 to 50, step 0.5.

Presets: Alto `0` · Tenor `0` · Bari `0` · Soprano `0`.

### Wrap picture around to the table (`top_image_wrap`)

Wrap the picture around the body like a label.

Range: on / off.

Presets: Alto `false` · Tenor `false` · Bari `false` · Soprano `false`.

### Text, right side (`side_text_right`)

Text on the right side (seen from above, tip away). Lines, variables as on top.

Range: text.

Presets: Alto `(empty)` · Tenor `(empty)` · Bari `(empty)` · Soprano `(empty)`.

### Text, left side (`side_text_left`)

Text on the left side.

Range: text.

Presets: Alto `(empty)` · Tenor `(empty)` · Bari `(empty)` · Soprano `(empty)`.

### Side text size (`side_text_size`)

Side letter height (mm).

Range: 1.5 to 10, step 0.5.

Presets: Alto `3.5` · Tenor `3.5` · Bari `3.5` · Soprano `3.5`.

### Side text position (`side_text_position`)

Side text from just behind the ligature: + toward the tip, - toward the shank (mm).

Range: -50 to 50, step 0.5.

Presets: Alto `0` · Tenor `0` · Bari `0` · Soprano `0`.

### Side text up / down (`side_text_vertical`)

Moves the side text up (+) or down (-) (mm).

Range: -10 to 10, step 0.5.

Presets: Alto `0` · Tenor `0` · Bari `0` · Soprano `0`.

### Lettering style (`lettering_style`)

Ligature and cap lettering; the mouthpiece's is always engraved (the ligature slides over it).

Range: `engraved`, `raised`.

Presets: Alto `engraved` · Tenor `engraved` · Bari `engraved` · Soprano `engraved`.

### Lettering depth (`lettering_depth`)

How deep the letters go, or how far they stand out (mm).

Range: 0.2 to 1.5, step 0.05.

Presets: Alto `0.5` · Tenor `0.5` · Bari `0.5` · Soprano `0.5`.

### Font (`lettering_font`)

Typeface. Keep script faces 5mm or taller.

Range: `Sans Bold`, `Sans`, `Serif Bold`, `Serif`, `Serif Italic`, `Mono Bold`, `Bebas Neue`, `Marcellus SC`, `Rozha One`, `Alfa Slab One`, `Audiowide`, `Black Ops One`, `Lobster`, `Pacifico`, `Kaushan Script`.

Presets: Alto `Sans Bold` · Tenor `Sans Bold` · Bari `Sans Bold` · Soprano `Sans Bold`.

### Lettering distance from the tip (`lettering_tip_clearance`)

Keeps lettering this far back from the tip (mm).

Range: 5 to 60, step 0.5.

Presets: Alto `22` · Tenor `22` · Bari `22` · Soprano `22`.

### Top text font (`top_text_font`)

The top text's own typeface; same = the Font above.

Range: `same`, `Sans Bold`, `Sans`, `Serif Bold`, `Serif`, `Serif Italic`, `Mono Bold`, `Bebas Neue`, `Marcellus SC`, `Rozha One`, `Alfa Slab One`, `Audiowide`, `Black Ops One`, `Lobster`, `Pacifico`, `Kaushan Script`.

Presets: Alto `same` · Tenor `same` · Bari `same` · Soprano `same`.

### Side text font (`side_text_font`)

The side texts' own typeface; same = the Font above.

Range: `same`, `Sans Bold`, `Sans`, `Serif Bold`, `Serif`, `Serif Italic`, `Mono Bold`, `Bebas Neue`, `Marcellus SC`, `Rozha One`, `Alfa Slab One`, `Audiowide`, `Black Ops One`, `Lobster`, `Pacifico`, `Kaushan Script`.

Presets: Alto `same` · Tenor `same` · Bari `same` · Soprano `same`.

### Text around the shank (`shank_text`)

Text around the shank's round band at the neck end (empty = none); variables as on top.

Range: text.

Presets: Alto `(empty)` · Tenor `(empty)` · Bari `(empty)` · Soprano `(empty)`.

### Shank text size (`shank_text_size`)

Shank letter height (mm); the band is short, so keep it small.

Range: 1.5 to 8, step 0.5.

Presets: Alto `3` · Tenor `3` · Bari `3` · Soprano `3`.

### Shank text around (`shank_text_around`)

Where around the shank the text is centred (degrees): 0 = top, 90 = right, -90 = left.

Range: -180 to 180, step 15.

Presets: Alto `0` · Tenor `0` · Bari `0` · Soprano `0`.

### Shank text font (`shank_text_font`)

The shank text's own typeface; same = the Font above.

Range: `same`, `Sans Bold`, `Sans`, `Serif Bold`, `Serif`, `Serif Italic`, `Mono Bold`, `Bebas Neue`, `Marcellus SC`, `Rozha One`, `Alfa Slab One`, `Audiowide`, `Black Ops One`, `Lobster`, `Pacifico`, `Kaushan Script`.

Presets: Alto `same` · Tenor `same` · Bari `same` · Soprano `same`.

### Shank decoration (`shank_detail`)

Decoration on the shank's band: rounded rings, V flutes along it, a spiral or knurling.

Range: `none`, `rings`, `flutes`, `spiral`, `knurled`.

Presets: Alto `none` · Tenor `none` · Bari `none` · Soprano `none`.

### Cut in or raised (`shank_detail_style`)

Shank decoration cut in (engraved) or standing out (raised).

Range: `engraved`, `raised`.

Presets: Alto `engraved` · Tenor `engraved` · Bari `engraved` · Soprano `engraved`.

### How many (`shank_detail_count`)

How many rings (as many as fit), flutes, spiral starts (up to 4) or knurl lines each way.

Range: 1 to 40, step 1.

Presets: Alto `3` · Tenor `3` · Bari `3` · Soprano `3`.

### Ring position (`shank_detail_position`)

Where a single ring sits: 0 = by the neck end, 1 = by the flare.

Range: 0 to 1, step 0.05.

Presets: Alto `0.25` · Tenor `0.25` · Bari `0.25` · Soprano `0.25`.

### Shank decoration depth (`shank_detail_depth`)

How deep the rings or flutes go, or how far they stand out (mm); 1.2mm of wall stays.

Range: 0.3 to 1.2, step 0.05.

Presets: Alto `0.6` · Tenor `0.6` · Bari `0.6` · Soprano `0.6`.

## Profile overrides

Point lists that replace a built-in curve: `[[distance from the shank end, value], ...]`, `[]` = the built-in one. Edit them in the app's **Curves** panel (OpenSCAD's Customizer can't edit lists).

### Bore axis height (`bore_axis_height`)

Only with your own top outline: bore height at the neck end (mm).

Range: 4 to 30, step 0.1.

Presets: Alto `14.5` · Tenor `14.5` · Bari `14.5` · Soprano `14.5`.

### Ext width points (`ext_width_points`)

Advanced: outside width along the length, [[distance, width], ...]; [] = built-in.

Range: text.

Presets: Alto `[]` · Tenor `[]` · Bari `[]` · Soprano `[]`.

### Ext top points (`ext_top_points`)

Advanced: top outline along the length, [[distance, height], ...].

Range: text.

Presets: Alto `[]` · Tenor `[]` · Bari `[]` · Soprano `[]`.

### Ext bottom points (`ext_bottom_points`)

Advanced: underside behind the table, [[distance, height], ...].

Range: text.

Presets: Alto `[]` · Tenor `[]` · Bari `[]` · Soprano `[]`.

### Ext widest points (`ext_widest_points`)

Advanced: height of each section's widest point, [[distance, height], ...].

Range: text.

Presets: Alto `[]` · Tenor `[]` · Bari `[]` · Soprano `[]`.

### Ext top squareness points (`ext_top_squareness_points`)

Advanced: squareness of the upper outside, [[distance, squareness], ...].

Range: text.

Presets: Alto `[]` · Tenor `[]` · Bari `[]` · Soprano `[]`.

### Ext bottom squareness points (`ext_bottom_squareness_points`)

Advanced: squareness of the lower outside, [[distance, squareness], ...].

Range: text.

Presets: Alto `[]` · Tenor `[]` · Bari `[]` · Soprano `[]`.

### Table width points (`table_width_points`)

Advanced: reed seat width along the length, [[distance, width], ...].

Range: text.

Presets: Alto `[]` · Tenor `[]` · Bari `[]` · Soprano `[]`.

### Interior width points (`interior_width_points`)

Advanced: inside width along the length, [[distance, width], ...].

Range: text.

Presets: Alto `[]` · Tenor `[]` · Bari `[]` · Soprano `[]`.

### Interior top squareness points (`interior_top_squareness_points`)

Advanced: squareness of the upper inside, [[distance, squareness], ...].

Range: text.

Presets: Alto `[]` · Tenor `[]` · Bari `[]` · Soprano `[]`.

### Interior bottom squareness points (`interior_bottom_squareness_points`)

Advanced: squareness of the lower inside, [[distance, squareness], ...].

Range: text.

Presets: Alto `[]` · Tenor `[]` · Bari `[]` · Soprano `[]`.

### Floor points (`floor_points`)

Advanced: floor to the window (can start before the throat), [[distance, height], ...].

Range: text.

Presets: Alto `[]` · Tenor `[[40, 3.4], [46, 3.2], [52, 2.9], [54, 1.8]]` · Bari `[]` · Soprano `[[29, 2.3], [31, 2.2], [33, 2.9], [35, 2.7], [37, 2.0]]`.

### Baffle points custom (`baffle_points_custom`)

Advanced: your own baffle, [[distance, height above the table], ...]; wins over the shape.

Range: text.

Presets: Alto `[]` · Tenor `[]` · Bari `[]` · Soprano `[]`.

### Facing gauge points (`facing_gauge_points`)

Advanced: your own facing (Gauge), [[mm from the tip, gap], ...].

Range: text.

Presets: Alto `[]` · Tenor `[]` · Bari `[]` · Soprano `[]`.

### Top adjust (`top_adjust`)

Shape edits (the app's "Edit shape"): mm added to the outline after the sliders, so the sliders keep working, [[fraction of the length, mm], ...]; 0 at both ends unless given there.

Range: text.

Presets: Alto `[]` · Tenor `[]` · Bari `[]` · Soprano `[]`.

### Underside adjust (`underside_adjust`)

Range: text.

Presets: Alto `[]` · Tenor `[]` · Bari `[]` · Soprano `[]`.

### Width adjust (`width_adjust`)

Range: text.

Presets: Alto `[]` · Tenor `[]` · Bari `[]` · Soprano `[]`.

### Baffle adjust (`baffle_adjust`)

Range: text.

Presets: Alto `[]` · Tenor `[]` · Bari `[]` · Soprano `[]`.

### Floor adjust (`floor_adjust`)

Range: text.

Presets: Alto `[]` · Tenor `[]` · Bari `[]` · Soprano `[]`.

### Chamber width adjust (`chamber_width_adjust`)

Range: text.

Presets: Alto `[]` · Tenor `[]` · Bari `[]` · Soprano `[]`.

## Manufacturing

### Thinnest wall (`min_wall`)

Thinnest wall allowed (mm). The inside shrinks to keep it.

Range: 1.2 to 4, step 0.1.

Presets: Alto `2.0` · Tenor `2.0` · Bari `2.0` · Soprano `2.0`.

### Extra to sand off (`print_stock`)

Extra on the table and facing to sand flat after printing (mm); try 0.1-0.2.

Range: 0 to 0.5, step 0.01.

Presets: Alto `0` · Tenor `0` · Bari `0` · Soprano `0`.

print_stock: 0 → 0.3 (heights stretched 6x)

*0 → 0.3 (heights stretched 6x)*

## Ligature

A ligature made to fit this mouthpiece (the app's **Ligature** section). See [the printing guide](PRINTING.md).

A ligature on the alto

### Ligature made (`ligature_made`)

A ligature is made for this design (the app shows it and offers its download).

Range: on / off.

Presets: Alto `false` · Tenor `false` · Bari `false` · Soprano `false`.

### Band length (`ligature_length`)

Length of the ligature band along the mouthpiece (mm), on its short side.

Range: 6 to 30, step 0.5.

Presets: Alto `12` · Tenor `12` · Bari `12` · Soprano `10`.

### Position (`ligature_position`)

Band's front edge (mm): 0 = just behind the window, minus = over the window.

Range: -10 to 40, step 0.5.

Presets: Alto `2` · Tenor `2` · Bari `2` · Soprano `2`.

### Thickness (`ligature_wall`)

Band thickness (mm): thinner flexes onto it more easily, thicker grips harder.

Range: 1.2 to 5, step 0.1.

Presets: Alto `2.0` · Tenor `2.0` · Bari `2.0` · Soprano `2.0`.

### Shape (`ligature_shape`)

D hugs the reed flat underneath; Round is a plain ring; Follows takes the body's shape.

Range: `d`, `round`, `conform`.

Presets: Alto `d` · Tenor `d` · Bari `d` · Soprano `d`.

### Tail toward the shank (`ligature_tongue`)

A tail on one side, running toward the shank (mm); 0 = a straight band.

Range: 0 to 15, step 0.5.

Presets: Alto `7` · Tenor `7` · Bari `7` · Soprano `5`.

### Tail side (`ligature_tongue_side`)

Which side the tail runs along: the top, or under the reed.

Range: `top`, `reed`.

Presets: Alto `top` · Tenor `top` · Bari `top` · Soprano `top`.

### Gap to the body (`ligature_fit`)

Gap between the band and the mouthpiece's body (mm); the reed is squeezed instead.

Range: -0.4 to 0.5, step 0.05.

Presets: Alto `0.1` · Tenor `0.1` · Bari `0.1` · Soprano `0.1`.

### Reed grip (`ligature_reed_grip`)

How hard the band presses the reed onto the table (mm): bigger = tighter.

Range: 0 to 0.6, step 0.05.

Presets: Alto `0.2` · Tenor `0.2` · Bari `0.2` · Soprano `0.2`.

### Text on the ligature (`ligature_text`)

Text on the ligature's top (empty = none). Lines, variables as on the top text.

Range: text.

Presets: Alto `(empty)` · Tenor `(empty)` · Bari `(empty)` · Soprano `(empty)`.

### Ligature text font (`ligature_text_font`)

The ligature text's own typeface; same = the Font in Personalize.

Range: `same`, `Sans Bold`, `Sans`, `Serif Bold`, `Serif`, `Serif Italic`, `Mono Bold`, `Bebas Neue`, `Marcellus SC`, `Rozha One`, `Alfa Slab One`, `Audiowide`, `Black Ops One`, `Lobster`, `Pacifico`, `Kaushan Script`.

Presets: Alto `same` · Tenor `same` · Bari `same` · Soprano `same`.

### Text size (`ligature_text_size`)

Ligature letter height (mm).

Range: 2 to 12, step 0.5.

Presets: Alto `4` · Tenor `4` · Bari `4` · Soprano `4`.

### Text direction (`ligature_text_angle`)

Which way the ligature's text reads: along or across (flipped = upside down).

Range: 0 to 270, step 90.

Presets: Alto `90` · Tenor `90` · Bari `90` · Soprano `90`.

### Picture on the ligature (`ligature_image`)

A picture (SVG file) on the ligature; same = the mouthpiece's top picture; empty = none.

Range: text.

Presets: Alto `same` · Tenor `same` · Bari `same` · Soprano `same`.

### Picture size (`ligature_image_width`)

Ligature picture width (mm).

Range: 3 to 30, step 0.5.

Presets: Alto `8` · Tenor `8` · Bari `8` · Soprano `8`.

### Picture height / width (`ligature_image_aspect`)

Picture height / width, for spacing (the app fills it in).

Range: 0.1 to 10, step 0.01.

Presets: Alto `1` · Tenor `1` · Bari `1` · Soprano `1`.

### Picture rotation (`ligature_image_angle`)

Ligature picture rotation (degrees).

Range: 0 to 345, step 15.

Presets: Alto `0` · Tenor `0` · Bari `0` · Soprano `0`.

### Text and picture position (`ligature_lettering_position`)

Moves the ligature's text and picture toward the tip (+) or the shank (-) (mm).

Range: -15 to 15, step 0.5.

Presets: Alto `0` · Tenor `0` · Bari `0` · Soprano `0`.

## Cap

### Cap made (`cap_made`)

A cap is made for this design (the app shows it and offers its download).

Range: on / off.

Presets: Alto `false` · Tenor `false` · Bari `false` · Soprano `false`.

### Goes over (`cap_ligature`)

What the cap goes over: the ligature made for this design, or a metal one.

Range: `printed`, `metal`.

Presets: Alto `printed` · Tenor `printed` · Bari `printed` · Soprano `printed`.

### Grip squeeze (`cap_grip`)

How hard the rim squeezes the ligature (mm): bigger = tighter; 0 = no squeeze.

Range: 0 to 0.5, step 0.05.

Presets: Alto `0.15` · Tenor `0.15` · Bari `0.15` · Soprano `0.15`.

### Slot side (`cap_slot_side`)

Side of the slot up from the rim, and of a metal ligature's screws: under the reed or on top.

Range: `reed`, `top`.

Presets: Alto `reed` · Tenor `reed` · Bari `reed` · Soprano `reed`.

### Slot length (`cap_slot_length`)

Slot up from the rim, for air and so the rim clips on: length (mm); 0 = none.

Range: 0 to 80, step 1.

Presets: Alto `30` · Tenor `30` · Bari `30` · Soprano `30`.

### Slot width (`cap_slot_width`)

Slot width (mm).

Range: 1 to 8, step 0.5.

Presets: Alto `3` · Tenor `3` · Bari `3` · Soprano `3`.

### Air holes in the end (`cap_end_vents`)

Air holes through the closed end, in a row (0 = none).

Range: 0 to 7, step 1.

Presets: Alto `3` · Tenor `3` · Bari `3` · Soprano `3`.

### End hole size (`cap_end_vent_size`)

End hole diameter (mm).

Range: 1 to 4, step 0.5.

Presets: Alto `2` · Tenor `2` · Bari `2` · Soprano `2`.

### Side vents (`cap_side_vents`)

Air vents on both sides, between the rim and the tip: slots along the cap, round holes, or none.

Range: `none`, `slots`, `holes`.

Presets: Alto `none` · Tenor `none` · Bari `none` · Soprano `none`.

### Vents on each side (`cap_side_vent_count`)

How many vents on each side (slots stack up the side, holes run along it).

Range: 1 to 5, step 1.

Presets: Alto `2` · Tenor `2` · Bari `2` · Soprano `2`.

### Vent size (`cap_side_vent_size`)

Vent width, or a hole's diameter (mm).

Range: 1.5 to 5, step 0.5.

Presets: Alto `2.5` · Tenor `2.5` · Bari `2.5` · Soprano `2.5`.

### Space between vents (`cap_side_vent_gap`)

Space between neighbouring vents (mm).

Range: 1 to 10, step 0.5.

Presets: Alto `3` · Tenor `3` · Bari `3` · Soprano `3`.

### Wall thickness (`cap_wall`)

Wall thickness (mm).

Range: 1.2 to 4, step 0.1.

Presets: Alto `1.6` · Tenor `1.6` · Bari `1.6` · Soprano `1.6`.

### Shape (`cap_shape`)

Follows the mouthpiece (smoothed), or round.

Range: `conform`, `round`.

Presets: Alto `conform` · Tenor `conform` · Bari `conform` · Soprano `conform`.

### Extra length (toward the shank) (`cap_extend`)

Lengthens the cap toward the shank (mm); the most covers the whole mouthpiece.

Range: 0 to 120, step 1.

Presets: Alto `0` · Tenor `0` · Bari `0` · Soprano `0`.

### Space at the end (`cap_end_gap`)

Space between the tip and the inside of the closed end (mm).

Range: 1 to 20, step 0.5.

Presets: Alto `4` · Tenor `4` · Bari `4` · Soprano `4`.

### End shape (`cap_end_dome`)

Closed end's shape: 0.6 = a low dome, 1 = a full dome as tall as the end gap (lower needs supports).

Range: 0.6 to 1, step 0.1.

Presets: Alto `1` · Tenor `1` · Bari `1` · Soprano `1`.

### Rim bead (`cap_rim_bead`)

A raised bead around the open end (mm out from the wall); 0 = none.

Range: 0 to 1.5, step 0.1.

Presets: Alto `0.6` · Tenor `0.6` · Bari `0.6` · Soprano `0.6`.

### Text on the cap (`cap_text`)

Text on the cap's top (empty = none). Lines, variables as on the top text.

Range: text.

Presets: Alto `(empty)` · Tenor `(empty)` · Bari `(empty)` · Soprano `(empty)`.

### Cap text font (`cap_text_font`)

The cap text's own typeface; same = the Font in Personalize.

Range: `same`, `Sans Bold`, `Sans`, `Serif Bold`, `Serif`, `Serif Italic`, `Mono Bold`, `Bebas Neue`, `Marcellus SC`, `Rozha One`, `Alfa Slab One`, `Audiowide`, `Black Ops One`, `Lobster`, `Pacifico`, `Kaushan Script`.

Presets: Alto `same` · Tenor `same` · Bari `same` · Soprano `same`.

### Text size (`cap_text_size`)

Cap letter height (mm).

Range: 2 to 14, step 0.5.

Presets: Alto `5` · Tenor `5` · Bari `5` · Soprano `5`.

### Text direction (`cap_text_angle`)

Which way the cap's text reads: along or across (flipped = upside down).

Range: 0 to 270, step 90.

Presets: Alto `0` · Tenor `0` · Bari `0` · Soprano `0`.

### Picture on the cap (`cap_image`)

A picture (SVG file) on the cap; same = the mouthpiece's top picture; empty = none.

Range: text.

Presets: Alto `same` · Tenor `same` · Bari `same` · Soprano `same`.

### Picture size (`cap_image_width`)

Cap picture width (mm).

Range: 3 to 40, step 0.5.

Presets: Alto `10` · Tenor `10` · Bari `10` · Soprano `10`.

### Picture height / width (`cap_image_aspect`)

Picture height / width, for spacing (the app fills it in).

Range: 0.1 to 10, step 0.01.

Presets: Alto `1` · Tenor `1` · Bari `1` · Soprano `1`.

### Picture rotation (`cap_image_angle`)

Cap picture rotation (degrees).

Range: 0 to 345, step 15.

Presets: Alto `0` · Tenor `0` · Bari `0` · Soprano `0`.

### Text and picture position (`cap_lettering_position`)

Moves the cap's text and picture toward the tip (+) or the shank (-) (mm).

Range: -30 to 30, step 0.5.

Presets: Alto `0` · Tenor `0` · Bari `0` · Soprano `0`.

### Band length (`cap_metal_length`)

Metal ligature: band length along the mouthpiece (mm).

Range: 6 to 30, step 0.5.

Presets: Alto `16` · Tenor `16` · Bari `16` · Soprano `16`.

### Band position (`cap_metal_position`)

Metal ligature: front edge, mm behind the window's back end.

Range: -10 to 25, step 0.5.

Presets: Alto `2` · Tenor `2` · Bari `2` · Soprano `2`.

### Band thickness (`cap_metal_proud`)

Metal ligature: how far the band stands out of the body all round (mm).

Range: 0 to 4, step 0.1.

Presets: Alto `1.2` · Tenor `1.2` · Bari `1.2` · Soprano `1.2`.

### Screws, width across (`cap_metal_screw_width`)

Metal ligature: width of its screws and their posts, across (mm); the slot widens to clear it.

Range: 4 to 30, step 0.5.

Presets: Alto `14` · Tenor `14` · Bari `14` · Soprano `14`.

### Screws, length along (`cap_metal_screw_length`)

Metal ligature: length of the screw block along the mouthpiece (mm).

Range: 4 to 30, step 0.5.

Presets: Alto `12` · Tenor `12` · Bari `12` · Soprano `12`.

## Output

What the file makes. The debug parts show the pieces the mouthpiece is built from.

### What to print (`part`)

What to make: the mouthpiece, a shank test ring, a ligature, a cap, or debug pieces.

Range: `mouthpiece`, `shank_test_ring`, `ligature`, `cap`, `ligature_seated`, `cap_seated`, `reed_model`, `ligature_clash`, `cap_clash`, `metal_ligature_model`, `interior_only`, `debug_exterior`, `debug_interior`, `debug_window_cutter`, `debug_window_only`, `debug_window_planform`, `debug_facing_cutter`, `debug_facing_only`, `debug_ext_minus_interior`, `debug_ext_minus_window`, `debug_ext_minus_facing`, `clearance_report`, `facing_report`.

Presets: Alto `mouthpiece` · Tenor `mouthpiece` · Bari `mouthpiece` · Soprano `mouthpiece`.

### Smoothness (`render_fn`)

Overrides the Quality menu once changed: higher is smoother but slower; 64 prints fine.

Range: 16 to 128, step 8.

Presets: Alto `64` · Tenor `64` · Bari `64` · Soprano `64`.

### Download standing on its neck end (`print_orientation`)

Stand it on its neck end, as printed. Off: lie it on the reed table.

Range: on / off.

Presets: Alto `true` · Tenor `true` · Bari `true` · Soprano `true`.

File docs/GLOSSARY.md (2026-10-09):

# Mouthpiece glossary

The names players and refacers use for the parts of a mouthpiece, and the settings in the app that
change each one. Settings are given by their name in the app; [PARAMETERS.md](PARAMETERS.md) has
every setting with pictures. Besides the sliders, **Shape charts** (under the view) show the facing,
the outside and the inside, and **Edit shape** lets you drag their lines.

Side view of the alto preset cut down the middle, with the reed in place: tip rail, tip opening, side rail, break point, facing curve, window, table, beak, baffle, chamber, floor, throat, bore, socket, body and shank

The alto preset seen from the reed side: tip rail, side rails, window, table and shank

## The reed side

| Part | What it is | Settings |
|---|---|---|
| **Table** (reed seat) | The flat where the reed's back lies and the ligature holds it. | **Table length**, **Table width at the tip**, **Table width at the back**, **Table hollow** |
| **Window** | The opening in the table under the reed, between the rails. | **Window length**, **Window width**, **Window narrows at the back**, **Window corner rounding** |
| **Side rails** | The two edges along the window that the reed seals on. | **Side rail width** |
| **Tip rail** (front rail) | The edge across the front that the reed closes against. | **Tip rail thickness**, **Tip roundness** |
| **Facing** (lay) | The rails' gentle curve away from the reed, from the break point to the tip. Both rails need the same curve. | **Facing curve**, **Where the curve opens**, or drag the points on the **Facing curve** chart |
| **Break point** | Where the rails leave the flat table: the start of the facing. | **Facing length** sets how far it is from the tip |
| **Facing length** | From the break point to the tip, in mm. | **Facing length** |
| **Tip opening** | The gap between the reed and the tip rail, measured with a straightedge on the table. Often given in thousandths of an inch. | **Tip opening** |
| **Chamfer** | A small bevel on the inside edge of the rails, around the window. | none: finish it by hand if you want one |

## Inside: the air path from tip to neck

| Part | What it is | Settings |
|---|---|---|
| **Baffle** | The roof over the reed, just behind the tip rail. Common shapes: flat, rollover (rounded), step (a ledge), concave (scooped). | **Baffle shape**, **Baffle height**, **Where the baffle begins**, **Baffle curve**, **Baffle hump** |
| **Floor** / **ramp** | The bottom of the inside, from the window's back edge to the throat. A ramp is a floor that slopes gradually away from the reed instead of dropping. | **Chamber floor**, **Chamber height**; the floor line in **Edit shape** (Inside chart) |
| **Side walls** | The inside walls on each side of the window, from the rails up to the roof: straight, leaning out (scooped) or leaning in. | **Chamber side walls** |
| **Chamber** | The open space between the baffle and the throat. Its cross-section can be round, square or horseshoe. | **Chamber shape**, **Chamber width**, **Widening after the throat**, **How far the full width runs**, **Chamber height** |
| **Throat** | The narrowest point inside, where the chamber meets the bore. | **Throat position**, **Throat width**, **Narrowing into the throat**, **Throat shape** |
| **Bore** | The round tube from the throat back to the socket. | **Bore (behind the cork)**, **Table angle to the neck** |
| **Socket** | The back of the bore, where the neck cork goes in. | **Neck cork diameter**, **Cork squeeze**, **How far the cork goes in**, **Lead-in at the opening** |
| **Inside air volume** | All the air from the neck's end to the tip, with the reed closed. Shown in the readouts. | the chamber, baffle and length settings together |

## Outside

| Part | What it is | Settings |
|---|---|---|
| **Beak** | The sloping top in front, from the tip back to the shoulder; it rests on the top teeth. | **Beak height at the tip**, **Beak curve**, **Beak top**, **Beak top width**, **Beak length** |
| **Shoulder** | Where the beak meets the body. | **Beak length**, **Shoulder smoothness**, **Shoulder sweep** |
| **Body** | The middle, at its widest and tallest; the ligature sits here. | **Body width**, **Body height**, **Body cross-section**, **Sides near the table** |
| **Shank** | The back end, around the socket. | **Shank outside diameter**; **Shank decoration** and **Text around the shank** (Personalize) |
| **Length** | From the neck end to the tip. | **Length** |

## Around it

| Part | What it is | In the app |
|---|---|---|
| **Reed** | Its heel lies on the table; its thin tip vibrates against the facing and tip rail. | **Table length** matches the table to it |
| **Ligature** | The band that holds the reed on the table. | **Ligature** (on the left) makes one to fit |
| **Cap** | The cover over the tip and reed. | **Cap** (on the left) makes one to fit |

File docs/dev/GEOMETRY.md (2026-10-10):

# Geometry notes (developer reference)

How the generator (`scad/lib/mouthpiece_base.scad`) works. Read before changing it or the presets.

## Construction

`exterior - interior - window_cutter - facing_cutter`. Every main solid is a **ring-stitched
polyhedron** (`ring_loft`: same point count and order per ring, consecutive rings stitched by index,
quad diagonals mirrored on the two halves so the mesh is symmetric). No `hull()` anywhere.

### Exterior

- **Rings.** `exterior_ring_at(z)` -> `[hw, top, bot, widest_y, n_top, n_bot]` (indices `E_*`),
  computed once per station. Superellipse rings (`sring`) with separate upper/lower exponents that
  meet at the widest point; points by angle, blended toward arc-length spacing only on ridged tops
  (exponent < 2), the weight averaged over ±8mm (`exterior_arc_w`; pointwise, it slid crest points
  into jagged triangles). Resolution from `render_fn`: `render_fn` points per exterior ring, ~0.75x
  per interior ring, spacing `Z_STEP = 64 / render_fn` (1mm at 64), plus 16 dense rings over the tip.
- **Outline** = the file's **shape tables** (`shape_width`, `shape_top`, `shape_bottom` behind the
  table, `shape_widest`, `shape_top/bottom_squareness`, each `[[fraction of L, value]]`) joined by
  **PCHIP** (monotone cubic: C1, no overshoot); an `ext_*_points` override replaces a curve. The
  app's shape edits (`top_adjust`, `underside_adjust`, `width_adjust`, and inside `baffle_adjust`,
  `floor_adjust`, `chamber_width_adjust`: `[[fraction of L, mm]]`, 0 at both ends unless given)
  add to the outline after every slider (`adjusted()`, resampled) or to the inside's own lines,
  always before the clamps, so every guarantee still holds (the baffle's printable-slope hold
  applies to them). A top or underside edit also stretches the section between them (`widest_followed()`:
  the widest point moves in proportion), so the flanks follow the crest instead of being squashed. An empty
  table stops with an assertion (`SHAPE_TABLES_OK`); there is no fallback. Knobs:
  `body_width`, `body_height` in mm (the body's widest / tallest table point; the scale that gives
  it, `size_k`, fades in across the flare so the tenon keeps its size; the fade is the flare's own
  progress, `flare_fade`, so a size change stretches the flare's curve instead of adding a hump),
  `beak_tip_height` (the top eases onto it over the last 40%), the three squareness values.
- **Tip.** Width x `tip_factor` (reed-tip quarter ellipse). The front edge rounds over (`tip_nose`
  1.2mm), since the rings close to a vertical line there. A ridged top (exponent < 2) eases to 2
  over 0.25 L before the tip (`tip_round_ease`, `exterior_top_exp_final`). The widest-point table
  keeps its end slope to the tip (`widest_table_at`; held level, it flattened the section into a lip
  line).
- **Beak sliders** (exact no-ops at 0): the shoulder is `shoulder_f(shape_top)`, the start of the
  top's steepest drop (knots from 0.3 L on). `beak_length` (mm, + = longer beak) moves it to
  `SHOULDER_F2` and stretches the top, widest-point and top-squareness tables to follow
  (`beak_remap`: piecewise linear between an anchor 0.3 L behind the shoulder and the tip; 0.2 L
  bunched the body into a bump). `beak_curve` (-1..1, + = scooped) resamples the top from
  `SHOULDER_F2` to the tip (17 knots) and subtracts a half sine of 12% of the beak's drop, so
  shoulder and tip stay put; the roof cap (guarantee 4) keeps the wall. With it and
  `beak_tip_height`, the widest point scales by the same ratio as the crest (`beak_sides_k`, vs
  `def_top0`), so the flanks follow the top (moving the crest alone left a groove / crease).
- **`shoulder_smoothness`** (0..1): the shoulder is the top table's steep drop plus the
  top-squareness table's boxier band behind it; both are replaced around the shoulder by a cubic
  matching value and slope at the ends of a window growing with the setting (10% of L behind, 22%
  in front at 1; `shoulder_smoothed()`), so 1 is a long even drop with nothing left on the flanks.
  A shape edit pushing the shoulder's corner down (`top_adjust`) raises it by the share of the drop
  taken away (`SHOULDER_SMOOTH`): a smooth pull over a sharp step left a double edge (a groove).
- **`beak_top_width`** (-1..1): scales the widest-point table over the beak (x0.55 at -1, x1.2 at
  +1; `beak_top_k()`, faded in across the shoulder): lower pulls the upper flanks in for a narrower,
  rounder top, higher fills them out. 0 = as designed.
- **`shoulder_sweep`** (mm, 0..20): the shoulder line runs down the flanks toward the tip. Behind a
  line slanting from the crest at the shoulder (`SWEEP_Z0`) to the widest point `shoulder_sweep` mm
  further on, the upper half is the same ring with a higher top exponent (+1.6 once past the
  shoulder's step, `SWEEP_ZK`), blurred over max(2.5, 0.4 x sweep) mm. Crest, widest point and width
  are unchanged. `sweep_pt` moves finished ring points outward along rays from the ring centre
  (star-shaped, only ever larger), so everything measured on `exterior_ring_at` stays safe; every
  surface-following part goes through it (exterior loft, `exterior_offset`, tooth pocket,
  `ext_ring_pt`). Check sections, not only angled renders: a version that delayed the top's drop
  dipped the crest into a channel.
- **Bore axis** is centred in the table's tenon (`eff_bah`); `bore_axis_height` only applies with
  `ext_top_points`. The shank end face is square to the tilted bore, built into the loft's first
  ring (no trimming boolean).
- **Shank outside**: `shank_diameter` scales the tables' tenon to that width at the neck end (and
  its heights about the bore axis), fading back to 1 across the flare (`shank_k`); the socket
  guarantee still grows it if thin. The old `*_scale` knobs are hidden multipliers for older files
  and links; src/migrate.ts turns an old file's into sizes (`outlineSizes`).

### Table, facing, window, socket

- **Table**: a flat reed seat from the table's back end (`L - table_length`) to the facing break, width set
  directly (`table_width_rear` -> `table_width_tip`): `table_bot_line` solves each ring's underside
  so the y = 0 chord is exactly that wide; a short scoop (`table_ramp`, 0.09 L) blends the underside
  from the tenon. `table_concavity` adds a half-sine hollow (reed heel to break) in the facing cutter.
- **Facing**: `facing_cutter` removes everything below the table plane and the facing curve
  (`facing_model` power/arc/gauge), lowered by `print_stock` when set. Gauge = PCHIP through
  `GAUGE_PTS`: [0, tip_opening], the user's points inside (0, facing_length) in order and never
  rising toward the break (clamped by construction), [facing_length, 0]; no points = power.
- **Window**: a slot (`window_width`, `window_taper`, `window_rear_radius`) whose front follows the
  reed-tip arc one `tip_rail_thickness` inside the tip; `window_cutter` (6-point rings) cuts it from
  below the table up to the interior's mid-height.
- **Socket**: `socket_d = neck_cork_diameter - shank_clearance` (a bigger "clearance" is a
  **tighter** fit: the cork's squeeze; the app calls it "Cork squeeze"), `eff_shank_depth` deep: the
  interior loft's first two rings (round, square to the tilted bore), then a short cone to the bore.
  **Entry bevel** (`shank_bevel` wider per side at the mouth, `shank_bevel_depth` deep; 1 x 1mm =
  45°): two extra rings that follow the tilted end face (points moved onto `end_face_z(y) + d`), the
  cone continued 0.5mm past the face so it crosses it cleanly. Clamped: `shank_bevel_eff()` leaves
  0.8mm of tenon wall at the face, `shank_bevel_depth_eff()` 3mm of full-size socket. Printed
  standing on the end face, the bevel is an overhang: fine at 45°, steep above ~60°.

### Interior

`interior_ring_at(z)` -> `[hw, top, bot, n_top, n_bot, narrow_hw, narrow_top]`: bore -> throat ->
chamber -> window region. `AIR_RINGS` (computed once) feeds the interior loft, the air-volume
readout and the clearance report.

- **Chamber** (`chamber_hw`): the space under the baffle from the throat to near the tip: throat
  width -> `chamber_width` at `chamber_peak_z` (throat + `chamber_flare` x (facing break - throat)),
  held to `chamber_end_z` (`chamber_full_length`; 40 = as far as it goes), closing by
  `L - tip_curve - 1`. Never narrower than the window above it. On the presets the chamber peaks
  under the window, so `chamber_flare` / `chamber_full_length` only show when `chamber_width` is
  wider than the window.
- **Wider than the window** (issue #1): under the window the walls hold the window width up to
  `narrow_top`, then open out to the chamber over 1.5mm or 2 x the step out (under ~45 degrees,
  no shelf over the rails); the wall fit there starts from `WIN_FIT_TAB`, its scale sampled every
  1mm and smoothed (lowest within 2mm, averaged over 1mm), so the width follows the outside in one
  curve instead of ribbing where ring points cross the window width. The fit still checks every ring.
- **Under the window** the walls rise straight from the window edge for 2mm (rails keep full
  thickness), then open out to the chamber width (`interior_points`); `sidewall_angle` (!= 0) leans
  them out or in from there (`sidewall_allowed`; leaning in, the window cutter's upper corners
  follow). The floor there is a 0.8mm skin above the facing that the window cutter removes.
- **`chamber_height`** (0 = round) acts between the throat and the window: full after the first 40%
  of that stretch, faded out over its last <= 4mm; where the baffle is already the roof the floor
  takes all of it (`chamber_roof_share`), so its effect is modest (alto 8.7 -> 9.1 cm³ from 8 to
  20mm; past ~16mm the floor is held by the underside wall). On the tenor and bari the window
  starts < 2mm after the throat, so it does nothing there: the app dims it when
  `overall_length - window_length - throat_position < 3`.
- **Round chamber section**: round until the chamber peak, then boxes up ([2,2] -> [4,6]) by the
  window start, over at least 6mm (a peak at or past the window start used to box up in one step,
  a ledge, on the tenor/bari/C-melody).
- **`floor_shape`** bends the built-in floor from throat to window (`floor_t`, t^(2^(1.5 s))).
  `floor_points` can start before the throat (the bore's round floor is used until its first point).
- **Throat**: `throat_shape` ("chamber" = as the chamber) gives it its own section, easing into the
  chamber's by the chamber peak or the window. The bore narrows into it over `throat_taper`.
- **Clamp order** (the socket is the fit on the horn, so it gives way last): the window shortens (to
  >= 15mm) to leave the socket + cone + 6mm, the throat moves forward past the socket end and back
  before the window (`eff_throat_z`), the narrowing shortens to what's left (`eff_throat_length`,
  >= 1mm), and only then the socket (`eff_shank_depth`). Each is a validate() note. `socket_d` /
  `socket_cone` are defined above all of these (a top-level variable read before its assignment is
  undef; this once hung every render).

### Baffle

The roof over the reed: `baffle_points_custom` if given, else the measured `shape_baffle`, or a
classic shape from `baffle_type` (flat / rollover / step / concave, `baffle_type_at`, between the
base curve's start and tip heights; concave = a 0.22 x drop bell at 62%). Every shape descends toward
the reed at a slope under ~0.85 (the step's face is a fixed 0.85 ramp): steeper would be an
unsupported ledge inside the part when printed standing up. Sliders: `baffle_height` (+ = closer to
the reed; eases in over the first third), `baffle_start` (moves where it begins; the tip end stays),
`baffle_hump` (a bell at 80% of the way to the tip), `baffle_curve` (u -> u^(2^c); held above a 0.85
descent from every point 16mm behind it, `baffle_shape_at`). The roof blends in from the
bore/chamber over 4mm and is smooth-maxed to stay >= 0.4mm above the reed line (`baffle_roof`).

**Texture** (`baffle_texture` along / across / dimples, `_style` engraved / raised, `_depth`,
`_spacing`; `baffle_texture_solid`, data `BTX_ROWS` after LETTERING_SPAN): dents cut up into the roof
(engraved) or bumps standing down from it (raised), from 4mm past the baffle start to 2mm behind
the tip curve (3mm fades). Each is a sphere cap (radius >= 3.5 x depth, so its sides stay under
~45° and no overhang is wider than the depth), placed square to the roof's local slope; grooves are
hulls of neighbouring spheres (1mm apart along, 0.75mm across). Per sample (`btx_row`): engraved,
the wall over it keeps 1.2mm (`BTX_WALL`; less than `interior_wall`, so the texture reaches the tip on a scooped beak) (+ the lettering depth within `LETTERING_SPAN`); raised, the
roof keeps 1mm above the floor and the reed line; either way the whole sphere stays within the air
path's width (the window's width under the window), so it never reaches the side walls or rails.
A dent the wall cuts to under 40% of its depth there is left out (a faint one looks like a speck);
grooves across take one even depth each, the shallowest along them (`btx_even`), so they end
cleanly instead of breaking up where the wall over the middle thins (a scooped beak).
Raised bumps are cut from the interior before it is cut from the body (they only fill air). The air
readout counts the texture (`BTX_AIR`, a grid integral of the caps, `btx_volume`; within ~20% of
the mesh at 1mm deep / 1.5mm apart, the arch of the roof unmodelled, i.e. <= 0.07 cm³). Costs
~0.3-1.3s per render.

### Readouts

- `validate()` warns when a guarantee overrode a parameter, and on: the chamber narrowed by the
  walls, Gauge without points, reed longer than the table allows, top text wider than the top / side
  text longer than the room (estimated at 0.62 x size per letter).
- "Inside air volume: X cm3" on every render (socket depth to tip, reed closing the window).
- Echo-only parts: `clearance_report` (thinnest wall), `facing_report` (facing gap per mm from the
  tip). `part` also has `shank_test_ring`, `interior_only` and `debug_*` pieces.
- `curve_editor_curves()`: every `*_points` override's curve as the model has it (interior curves
  sampled from `AIR_RINGS`, i.e. after the clamps); only evaluated when echoed (the app's Points
  panel). Add new overrides to it.
- `param_focus()`: for "zoom to parameter": per parameter/list a box (design frame), a view side and
  whether it's inside (cut), plus the print transform. Add new parameters to it.

### Lettering and pictures

- **Text** (tab "Lettering"): `top_text`, `side_text_right/left` (right = -X, the player's right
  looking down on the top with the tip away), `{tip}`/`{tip_mm}`/`{facing}`/`{chamber}`/`{length}`
  fill-ins (`fill_tokens`), engraved (default) or raised. Each text is a straight prism (down onto
  the top / in from a side) acting only in a skin that follows the surface: engraved = prism minus
  `exterior_offset(.., depth)` (the exterior shrunk inward), raised = prism inside the grown one.
  Clipped by `lettering_zone` lofts to z in [2, L - lettering_tip_clearance]; the top zone sits above
  a split 55% up from the widest line, as wide as the body there; the side zone runs from
  max(3.5, underside + 1) to 0.5mm below the split (top and side cuts meeting along an edge made
  holes; a raised letter below the split floated loose). Engraving leaves >= 0.8mm of
  `interior_wall()`.
- **Slanted cuts** (`slant`, `slanted_top`): the flat top picture, top text and side text are cut
  slanting toward the shank (`TOP_SLANT` = tan(45° + `bore_tilt`), `SIDE_SLANT`), so standing on the
  neck end every roof rises >= 45° outward: straight cuts left flat ledges and, on the top (tipped
  down by `bore_tilt` as printed), thin bits between strokes that started in mid-air (slicers'
  "floating regions"). Each shears about a plane through the surface, so the outline stays put; the
  top in 2mm strips across, each about the surface's chord (the top is crowned). Not the wrapped picture.
- **Top picture**: `top_image` = an SVG name in `scad/art/`, imported as `"../art/" + name`,
  `center = true`, `resize([top_image_width, 0], auto = true)`, cut like the top text. OpenSCAD can't
  measure an import, so `top_image_aspect` (height / width) is filled in by the app's picker; it only
  spaces picture and text (picture toward the tip, 2mm apart). SVG rules (filled shapes, holes as
  subpaths) are in `scad/art/README.md`. Quirk: several import()s of computed file names in one for
  loop all gave the first file. User uploads live in the browser and are sent per render.
- **Wrapped picture** (`top_image_wrap`): the picture's x becomes the distance around the body from
  the top centre, measured on the exterior ring at `top_image_z` (`WRAP_PTS`/`WRAP_CUM`,
  `wrap_frame(u)`). Cut into 1mm strips, each a wedge-shaped prism along that point's inward normal
  (`linear_extrude(scale = ...)`; parallel strips left uncut slivers, genus 3-12), clipped by
  `wrap_zone` down to `wrap_floor`. One measuring ring, so a picture much taller than the body
  distorts toward its ends; one covering the whole body can still give genus 3 (accepted).
- **Fonts**: `lettering_font` is a dropdown of 15 names (`LETTERING_FONTS`; an unknown name is used
  as is, desktop only), all SIL OFL in `scad/lib/fonts/`, registered by `use <fonts/...>` at the top
  of the base (Liberation is not bundled with the WebAssembly build). In the wasm build a missing
  font, and some font files (Cinzel, Abril Fatface, Righteous, Titan One, Bungee, Russo One, Passion
  One, Monoton, Bowlby One), crash the render ("null function"): test every new font there.
  `bundle_scad.mjs` drops the font `use`s.
  Each text can have its own (`top_text_font`, `side_text_font`, `shank_text_font`,
  `ligature_text_font`, `cap_text_font`; "same" = `lettering_font`, via `font_name()`).
- **Shank band** (`SHANK_BAND`): the stretch at the neck end (round, unless the body is boxy), from 1mm past the socket's
  lead-in to where the width starts to flare (at least 7mm: the bari's and soprano's shanks flare
  from the end, so they get that much of the flare; `shank_detail_length` > 0 sets the end instead), short of the reed's heel. `shank_detail` cuts
  grooves into it (`rings`: half-round, as many as fit up to `shank_detail_count`, one at
  `shank_detail_position`; older files' `ring` = rings, 1; `flutes`: V grooves along it; `spiral`:
  1-4 half-round starts from the band's start (clear of the end face), fading in and out over a half turn (`sd_taper`); `knurled`: V grooves both ways). Each is a tube swept over the surface
  (`sd_sweep`: a profile per slice, placed from the surface under each point, `sd_r` from the
  `SD_RGRID` of surface radii by station and angle, in the tilted bore frame): the band is only round on a round body, and
  details built around one circle cut deeper and wider at a boxy body's corners. Profiles reach
  only ~1mm past the surface (wide ones fold over themselves on a twisted path). And
  `shank_text` runs around it (2mm strips wedged out along the radius, as the wrapped picture; read
  with the tip up; `shank_text_around` turns it, + toward the right side). Both cut a skin
  (`exterior_relief`: `exterior_offset` with its own depth per station; grooves have 45-degree
  sides, so they print standing on the shank end) at most `SHANK_WALL - 1.2` deep. With text and a
  detail, the text takes the flare end of the band. The rings and flutes run from the end face
  (`SD_SPAN`, -1 on the axis): engraved, each is only as deep as `shank_room` allows (the socket's
  lead-in thins the wall there; 1.2mm stays), flutes open out through the face.
  `shank_detail_style = raised` adds them instead (`shank_raised`: square-sided rings or ribs,
  their tops `exterior_offset` outward by the depth, clipped at the end face; unioned with the
  exterior before the cuts).
- **Braces in strings**: OpenSCAD's parameter export stops at a string containing `{`, dropping
  every later parameter from the Customizer. Files write it `"{tip}"` (`make_variants.mjs`'s
  `fmt`, the app's `scadLiteral`); OpenSCAD reads the same string.

### Ligature

`part = ligature | ligature_seated | reed_model | ligature_clash`; `ligature_made` only records
that the design has one (no geometry reads it). A friction-fit ring made for the model, after
Windy City Woodwinds' printed ring: round inside, a band (`ligature_length`, 12mm; soprano 10) with a
tongue toward the shank (`ligature_tongue` +7mm; soprano 5), on top by default; 2mm wall. `ligature_shape`: "d"
(default: round over the top, following the reed underneath), "round", "conform" (follows the body).
Edges (`lig_edge_cut`, `lig_ts`): the rear edge (on top when printed) rounded outside, radius
`LIG_EDGE_R` (1mm, at most 0.45 x the wall); the front edge (on the plate) a 45° chamfer outside
(`LIG_EDGE_C`) and 0.3mm inside (eases it over the reed); each corner measured from its own edges.

- **The reed is the tight spot**: the reed counts `ligature_reed_grip` + `ligature_fit` thinner, so
  the band squeezes it by the grip (0.2) while the body keeps the fit gap (0.1). The band first
  touches the reed grip / taper mm in front of its seat (the readout says how far).
- **Support functions**: per station (1mm apart, band rear to tip) h(phi) over 1.5 x render_fn
  directions: the body's outline above the table (`ext_ring_pt`), the table edges, a reed (flat top
  at y = 0, arched bark: `LIG_REED_T` (3mm, any reed: the taper fit takes the difference) in the
  middle, 0.65 of it at the edges; the table's width), raised
  lettering's depth and a 0.03mm margin. A running max **from the tip back** makes each station
  contain everything in front of it, so the band always slides on over the beak. Inside = h +
  `ligature_fit`, outside = inside + `ligature_wall` (an outward offset of a convex shape: can't
  self-intersect). Round: the smallest midline-centred circle around the support (ternary search;
  R(c) is convex). D: max of the body+reed support and the upper half of the smallest circle around
  the body alone.
- The tongue makes the rear edge non-planar, so the band is one `tube_loft` polyhedron, intersected
  with a box so Manifold validates it and reports the genus.
- **Placement**: front edge `ligature_position` behind the window's rear end, clamped onto the reed
  (rear >= table_rear_z + 1) and behind the tip (front <= L - 8), shortening with a WARNING if
  needed. Echo: `LIGATURE <length> <front vs window> <inside W H rear> <W H front> <girth> <mm
  forward per 0.1mm thicker reed> <mm forward of the seat at first reed contact>`.
- `ligature` stands on its flat front edge for printing (tongue up); `ligature_seated` and
  `reed_model` get the mouthpiece's print transform so the app overlays them; `ligature_clash` =
  band ∩ mouthpiece, which `npm run check` requires to be empty. Module-local, so mouthpiece renders
  don't pay for it.
- **Lettering** (`ligature_text` (+ `_size`, `_angle`), `ligature_image` (+ `_width`, `_aspect`,
  `_angle`), `ligature_lettering_position`): on the band's top, in the mouthpiece's font, style and
  depth; picture toward the tip, text toward the shank, 2mm apart. Straight prisms
  (`lig_art_prisms`) from the band's widest line, acting in a skin = `tube_loft` between the band's
  rings at two offsets (engraved: outer + 1 down to outer - depth, depth clamped to leave 0.8mm of
  wall; raised: outer - 0.2 up to outer + depth), 0.8mm inside both edges (`lig_ring_t(.., inset)`).
  Two closed solids subtracted instead left a loose sliver. `art_2d(name, width, angle)` is the
  shared picture import. Without lettering the band is built exactly as before.

### Cap

`part = cap | cap_seated | cap_clash | metal_ligature_model`; `cap_made` only records that the design
has one (the app shows `cap_seated` see-through on the mouthpiece, like the ligature). A shell over
the tip, the reed and the ligature, as a store-bought cap: one smooth taper with a slot up from the
rim, side vents and air holes in the end; the rim clips onto the ligature. Built like the ligature from **support
functions**: per station (1mm, rim to tip) h(phi) = what the cap must clear: the whole body (behind
the table; above it plus the table's edges on it), **any reed** (`CAP_REED_T` = 4mm at the heel,
`CAP_REED_HW` = 0.5mm wider than the table a side), and the ligature: the printed one's outside (its
own `lig_h_at` + fit + wall) or a metal one's band (+ `cap_metal_proud`). A running max from the tip
back (inclusive) makes each station contain everything in front of it, so the cap slides on;
inside = that + `CAP_CLEARANCE` (0.5), shaped by `cap_shape` (conform, or `lig_round`).
- **Hull** (what makes it look like a moulded cap): per direction, the least concave majorant along z
  (`cap_majorant`, a monotone-chain upper hull over the stations and the dome's rings). That is the
  cross-section of the 3D convex hull of everything inside, so it is a valid support at every station
  and never grows toward the tip (the cap still slides on). Without it the running max stepped hard
  at the ligature's front edge (a drum, then a shoulder) and followed the beak's hollow top slope
  (a hooded look). It stops narrowing `CAP_HOLD` (6mm) behind the tip (the beak's rounded tip
  pinched it to a pencil point).
- **Collar** (over the ligature's band, inside only; the outside follows the hull: `pmax` + wall):
  inside = max(strictly-ahead running max + 0.05 - `CAP_FLEX`, own support - `cap_grip`), then
  `cap_tighten` (a few passes: support lines moved inward can stop touching the shape). The shell
  may be pushed out `CAP_FLEX` (0.4mm) on its way over what is ahead, so the full grip is reached (the
  readout's last number is the peak; a WARNING when under half the request).
- **Closed end**: a dome (`cap_end_dome` 0 = flat, 1 = full; `cap_end_gap` tall): the last ring scaled
  about its smallest-circle centre (`s = 1 - 0.7 dome (1 - cos psi)`, z = gap sin psi), the outside
  the same shifted by the wall (xy wall cos psi, z wall sin psi, so the wall never thins). Scaling a
  support function is always valid; an inward offset made neighbouring corners cross (genus -1..-5,
  "NotManifold") on the thin tip rings. The cap prints standing on its rim (the tip end is a poor base).
- **Slot**: from the rim on `cap_slot_side` (reed = under the reed, where a standard ligature's screws
  are; top = an inverted one's), `cap_slot_length` long, kept 3mm short of the dome; a prism from the
  table plane (y = 0 is inside the cap at every station) outward. Over a metal ligature it starts as a
  window `cap_metal_screw_width` + 1.6 wide, straight to 1.5mm past the screws' front end, then
  rounded. The screws are NOT in the support (they come in at the rim and ride in the window), so
  the cap stays the size of the band. `metal_ligature_model` is a stand-in (band, screw block, two
  screws) that `cap_clash` checks against.
- **End vents** (`cap_end_vents`, `cap_end_vent_size`): a row along x on the dome's centre line, each a
  cylinder along z from the dome's base out through the dome, within 55% of the ring's half-width;
  fewer fit = a WARNING. **EXPECTED GENUS** = the end vents + 2 x the side vents (the slot starts at
  the rim: no genus).
- **Side vents** (`cap_side_vents` none (the default) / slots / holes, `cap_side_vent_count` per side,
  `cap_side_vent_size`, `cap_side_vent_gap` between neighbours; back since 2026-10-09 with the placement automatic): both sides, on the side's
  middle line (`cap_side`: the middle of the ring's flattest side), from 2.5mm in front of the collar
  (the grip stays whole) to 3mm short of the tip. Slots run along the cap (up to 22mm, straight between
  the side's middle at their two ends) and stack up the side within 45% of the inside height; holes
  run along it, centred; both `cap_side_vent_gap` apart; fewer fit = a WARNING. Each is a bore from
  the middle out plus a 45° chamfer at the outside (`cap_ring_x`: the outline's reach at that height).
- **Pictures**: `ligature_image` / `cap_image` = "same" (the default) use `top_image` and its aspect
  (`LIG_IMAGE`, `CAP_IMAGE`); "" = none.
- **Lettering**: as the ligature's, on a skin between the outer rings at two offsets.
- **Rim bead** (`cap_rim_bead`, 0 = none): the outer rings near the rim pushed out by the bead,
  `CAP_BEAD_W` tall, then back at 45° (on the plate: no overhang); the bottom corner chamfered 0.3mm.
  Extra outer rings there (`out_zs`). **End shape** is clamped to 0.6..1 (`dome`): flatter left a flat
  ceiling ~25mm across (measured: 181 mm² facing straight down at 0, 84 at 0.6, 38 at 1).
- `cap_clash` = cap ∩ mouthpiece + cap ∩ the printed or stand-in metal ligature; `npm run check` runs it
  with `cap_grip=-0.05` (a squeeze of 0 touches the band's face exactly and leaves zero-thickness
  slivers) and accepts under 1mm³. `npm run sweep -- --part cap` sweeps the Cap and Ligature groups.
- Removed after review (2026-10-04): reed thickness / width (any reed now), a body fit (never
  gripped over the printed ligature), collar length and slits, room inside, ribs, the D
  shape: the slot and end holes do their jobs.
- Everything lives inside `cap_part()` (module-level values), so mouthpiece renders don't pay for it.

## Parameters

- **`*_points` overrides** are `[[z, value], ...]`, PCHIP-joined, prepared once (`pchip_prep`) and
  evaluated with `pchip_at` (binary search); add new ones the same way (and to
  `curve_editor_curves()`). The Customizer can't edit nested lists; the app's Points panel (Exact points) can.
- **Renamed parameters** (2026-09-26): chamber_d -> chamber_width, bore_d -> bore_diameter,
  throat_z -> throat_position, throat_length -> throat_taper, chamber_position -> chamber_flare,
  chamber_length -> chamber_full_length (0 "all the way" -> 40), tip_thickness -> beak_tip_height,
  tip_round -> tip_curve, side_text_height -> side_text_vertical, baffle_rollover -> baffle_hump.
  The app rewrites old names in files, saved designs and links (`src/migrate.ts`); the base declares
  the old names undef and warns if a file sets one (`RENAMED_PARAMS`).
- **Chamber width** (2026-10-10): `chamber_width` is in mm and independent of the throat (Throat
  width moves only the throat; a chamber narrower than the throat is allowed). From 2026-10-03 to
  10-09 it was `chamber_width_extra` (vs the throat, so the chamber followed it): the base keeps it
  hidden (undef; a file that sets it gets throat + extra), and the app converts files (text),
  sessions (no `chamberMm` mark) and links (no `cw` mark) to the width they made, using the
  design's own text or `CHAMBER_BEFORE` (what each project file had then).

## Presets

- The four presets' sizes were measured from Windy City Woodwinds' "64" models (credited in
  README.md) and entered as coarse shape tables: ~6-14 stations per curve (z as a fraction of L to
  0.005, values to 0.1mm), smoothed by hand. Tip openings are the models' nominal sizes (.076" /
  .095" / .110" / .065"); every voice uses facing exponent 1.8 with the measured curve length.
- Chambers: `bore_diameter`, the throat settings, `chamber_width` and a few `floor_points` follow
  the measured floor, roof and width along the bore within ~0.3mm. `chamber_width` is the typical
  width under the baffle (alto 13.8, tenor 14.8, bari 15.4, soprano 11.6), not the maximum. The
  bari's bore is a cone: `bore_diameter` 16.9 + `throat_taper` 55.
- Inside air volume: alto 9.0, tenor 10.2, bari 17.0, soprano 2.9 cm³.

### Variants

`scad/variants/<voice>_<family>.scad`, generated by `scripts/make_variants.mjs` from the voice file
(re-run it, don't edit the files). Neutral names, no sound claims; named for their element
badges (Latin flame, forest, wave). Until 2026-10-08 they were Ash, Birch, Cedar: `migratePath`
(src/migrate.ts) opens old paths in stored sessions and share links. **Settings only**: every
difference from the preset is a setting the app shows; the hidden shape tables stay the preset's,
so anyone can rebuild a variant (or take it further) in the app.

- **Flamma** (big chamber): closer tip, arc facing, round chamber and throat with scooped sidewalls
  (`sidewall_angle` 8, soprano 6), concave baffle; slimmer (width x0.95), round, a smooth full beak with no
  shoulder (`shoulder_smoothness` 1, `beak_curve` -0.3, `beak_length` +8% of L); two rings on the
  shank; 3.4% shorter.
- **Silva** (small chamber): more open tip, square chamber and abrupt square throat, rollover
  baffle + hump, thin tip rail; boxy (squareness 3.2 / 3.0 / 2.2), lower, a crisp set-back shoulder
  (`beak_length` -3% of L) swept down the sides, wide flat beak top; 16 raised knurls on
  the shank; 3.4% longer (bari: the preset's length, as length adds air there).
- **Unda** (all-round): close tip, short facing, flat baffle, 1.2mm rails; wider and soft, a
  softened shoulder into a scooped beak (`beak_curve` 0.7); a spiral on the shank.

Each carries side text (name / `{tip} {voice_letter}`, a font per family) and a picture on top, one set of
round element badges (`scad/art/element_*.svg`: Flamma fire, Silva leaf, Unda water; 12mm on the alto),
centred with the side text on one station just behind the ligature, the picture clear of its
tongue (`make_variants.mjs` reads both spots from an echo-only run and sets the `*_position`s). Sizes go as a fraction of the preset's
and `beak_length` as a fraction of L, so the four voices match. Guardrails: tip within ~.010" of
the preset, air within ±8% (baffle height is the main lever, ~±10% per mm; chamber width barely
moves it), thinnest wall >= ~1.2mm. The lengths go against each recipe's air (~5% per 3mm on the
alto), so all sit near the preset on the cork; a shorter Flamma stops at what the reed needs (table
start >= 0.16 L) and moves the throat (and the bari's bore cone) with the window. The classic baffle
types add air on the smaller voices (soprano flat +21%), so those variants take a negative
`baffle_curve` and keep the preset's chamber/throat widths.

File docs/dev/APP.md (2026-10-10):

# App notes (developer reference)

How the app works. Read before changing `src/` or `vite.config.ts`.

## How it runs (no server)

OpenSCAD runs in the browser, the project comes from the site, and the user's files and pictures
stay in their browser. Nothing may be saved on a server. `npm run dev` is plain Vite; a build is a
static site (docs/HOSTING.md).

- **Code map**: `src/api.ts` (the `Api` interface; `api` = `browserApi`). `App.tsx` holds the state
  (tabs, values, layout, B) and both layouts; `src/app/files.ts` (tabs, names, labels, downloads),
  `src/app/session.ts` (what is kept in this browser); hooks in `src/hooks/`: `useModelRender` (the
  render loop: one render per change, the readouts' reports, the ligature, download renders),
  `useParamFocus`, `useValueHistory` (undo/redo), `useMediaQuery`; toolbar and panel pieces in
  `src/components/`.
- **OpenSCAD**: the official WebAssembly build, pinned in `scripts/fetch_openscad_wasm.mjs` (version
  + SHA-256; bump together) into `public/openscad/` (gitignored; fetched once by `npm run dev`).
  `src/wasm/openscad.worker.ts` compiles the wasm once per worker and makes a fresh instance per job
  (main() runs once), files in MEMFS under `/scad` (cwd, so log paths are project-relative),
  outputs in `/tmp`. `src/wasm/runner.ts`: two lanes, "render" and "quick" (params, echo, picture
  measuring), one worker each, jobs in order; abort = terminate the worker. Every run gets the
  project, the user's files, their pictures (`art/<name>`) and the unsaved buffers; a file from the
  device is written at the root as `__local__<name>` so `include <lib/...>` still works. No
  COOP/COEP headers needed. The `-node.zip` build fails on Windows Node 21; the web build is the
  target.
- **Project files** = `scripts/project_files.mjs` (scad/ minus local folders; the presets list
  includes every `variants/*.scad`). Dev: the `liveProject` plugin in vite.config.ts serves them
  from scad/ at `project/` (manifest per request, so generator edits show on the next render).
  Build: `scripts/build_static_project.mjs` copies them to `public/project/` + `manifest.json` (+
  picture aspects measured natively when OpenSCAD is installed).
- **Settings lists made ahead**: `scad/param_lists.json` (committed; `npm run check` or
  `node scripts/param_lists.mjs` refreshes it) holds each preset's `.param` export with a hash of its
  text; `browserApi.params` uses it while the text matches (saves ~3s in the browser before the
  settings show), else asks OpenSCAD. A stale entry is just slower, never wrong.
- **Speed**: the browser takes ~2.5-3x native (alto ~2.5s, bari ~4.5s; a 4x-throttled CPU, like a
  phone, ~13s).

## Files and saving

- **Storage**: the user's files in localStorage `open-mouthpiece-files-v1` ({path: {text}});
  pictures in `open-mouthpiece-art-v1` (`userArt.ts`, shown via data: URLs); the session in
  `open-mouthpiece-session-v1` (was `scad-playground-v2`, read once). `files()` returns `{files,
  readOnly, own}`. On a phone over the LAN, storage is the phone browser's.
- **Save writes only the user's own files**; a project file (presets, `lib/`, ...) goes through
  Save as (`my_<name>`); a stored copy of a project path is ignored, so the site's project always
  wins. The base can be edited in the editor for live experiments (the unsaved text goes with every
  render), not saved.
- **Read-only presets** (`READ_ONLY` in scripts/project_files.mjs: the four voices and the variants,
  labelled "Alto Flamma" by `voiceLabel`): Save disabled, CodeMirror read-only, 🔒 on the tab;
  Customizer values still apply as -D overrides. Unsaved preset text in localStorage is dropped on
  load (a broken curve edit once stopped the tenor rendering). The CLI scripts still write them.
- **A saved design is a document**: Save and Save as write the Customizer values into the file
  (`withValues`, src/scadText.ts; a name the file doesn't assign goes under `/* [Hidden] */`) and
  clear them, so Reset means "back to what I saved". Save as leaves a preset as published (Compare
  with a preset also uses it as published); your own design keeps its unsaved changes. Typed names
  are made file-safe (`scadFileName`); own designs show with spaces for `_`.
- **Save as panel** (`saveDesignAs`, SaveAsPanel.tsx; the code column's Save as keeps a plain name box): a name,
  kept in this browser only; files are in Download ▾.
- **Download .scad** writes one self-contained file that opens in any OpenSCAD (`bundleDesign`,
  src/bundle.ts, the method of scripts/bundle_scad.mjs): a header, the file with its values, then
  the base without the defaults the file sets (unsaved tab text wins). Lettering is text(); a
  picture stays a file imported from `art/<name>` next to it (the header says so; without it
  OpenSCAD makes the model without the picture). The font `use<>`s are dropped (the header names a
  non-built-in font); the app registers its fonts for any main file without an include or a .ttf
  use<> (browserApi `workspace`), since a missing font crashes the wasm build. Named
  `my_<preset>.scad`, ~85 KB. Renders identically in the nightly; OpenSCAD 2021.01 renders it too.
- **Open .scad…** (or drop) loads .scad files as tabs, listed under "Open files" in the voice
  picker; an opened file gets Save (to Your designs) and Close. "Download tab" = the editor text as
  is.
- **Download ▾** (`downloadItems` in App.tsx, DownloadPanel.tsx; desktop: the ▾ joined to Download, phone: the
  ☰ menu): ticks for the mouthpiece STL, shank test rings, the ligature / cap once made, the design file
  (.scad + `art/`), the check card, a settings-only .scad under "More formats" (`<name>_settings.scad`: the
  voice file with the values, `include <../lib/` rewritten to `include <lib/`); more than one file = one zip (fflate: Chrome holds back a second download); one
  Download (`downloadFiles`), "Tick all" = the print kit. Ticks persist (`downloads` pref). The main
  button still downloads the part tab's part (and shows any download's progress). A file finished
  after the click's activation expired (`navigator.userActivation`) waits for a Save button in the
  status line (`deliver`): browsers block late script downloads.
- **Print kit** (`downloadKit` = `downloadFiles(DOWNLOAD_ALL)`, src/printKit.ts; Printing section):
  one zip with the mouthpiece, shank test rings at squeeze 0.10 / 0.20 / 0.30 (plus the design's own),
  the ligature and cap if made, the design file, and `<name>_check_card.txt` (tip, facing, length, air, thinnest wall, cork /
  socket, feeler-gauge stops) from one echo-only run (`kitReports`).
- **Top bar**: Save (own design), Save as… (always), Open…; a saved design also Close and Delete
  (`api.remove`). Discarding or deleting takes a second click. Switching voices closes the previous
  preset's tab when untouched; values stay in `valuesByKey`.
- **Old parameter names**: `src/migrate.ts` rewrites them in the session, stored files, opened and
  compare files, and share links. It must not touch the generator's own `RENAMED_PARAMS` block
  (that once hung the app on re-opening a download; `npm run check` guards it).

## The screen

- **One screen**: you go as deep as you open. Top bar = logo, voice picker (a design with unsaved
  settings shows "(edited)", so a changed preset isn't mistaken for the published one), file
  actions | Share, Download STL ▾, More ▾ (`components/Menu.tsx`), ⚙ (`AppearanceMenu.tsx`). Right panel
  (`DesignPanel`): readouts strip, "Find a setting" (opens matching sections, also searches All
  parameters), Undo/Redo, Auto-zoom, Reset, Expand/Collapse all, Descriptions, then folds (`Fold`,
  closed by default, summary from `DesignSection.summary`, ● count of changed settings): the
  sections (`DESIGN_SECTIONS`: the main settings, most useful first, then a nested "More" fold
  with the rest of the section, `DesignSection.more`; longer sections are `grouped()` into
  `DesignSection.groups` (Baffle, Chamber, ...: a small heading, the group's rows, its own More,
  fold id `m:<section>:<group>`; a group with no rows shows only its More, named after it;
  `chart` = the section's chart follows that group; `items` / `more` are derived from the groups,
  so the rail, badges and checks read them as before); every generator setting has exactly one place,
  checked by `npm run check`), Exact points, Compare A/B (while a B is pinned). The panel's left
  edge drags (`panelW`). UI prefs in `src/uiPrefs.ts` (`open-mouthpiece-ui-v1`).
- **Code column** (left, closed by default): editor + console. Opening it (`coding`) brings back
  the Render button and Auto, the full status line, parameter names, the point-list group and every
  dropdown value, and Save as acting on the editor's tab. Tabs are named by role (`tabLabel`):
  the design's name, or "Generator" for `lib/mouthpiece_base.scad`. One quiet line above the editor
  (`fileNote`) says which it is; keep such hints to one short line. Open project file… is grouped
  Presets / Variants / Your designs / Generator. A preset or variant on screen has no × (`canClose`:
  closing the only design left nothing to render); your own or an unsaved design closes to its
  voice's preset (`presetFor`, `replaceWithPreset`: loaded first, no flash).
- **Status**: render progress and errors are the status (`useModelRender`); what a user action did
  (saved, link copied, delete prompts) is a *notice* shown in its place for 4s. Errors clear it.
- **Settings**: `DesignPanel` = the curated controls in `src/design.ts` (labels, `caption`,
  `optionLabels`; `tip_opening` in thousandths via `ThouInput`, which takes mm too: a number under
  10; `part` limited to mouthpiece / test ring / ligature / cap unless the code is open; ranges and
  descriptions from the `.param` export). Typed numbers are clamped to the slider range. Labels from
  `paramLabel()`. A parameter that does nothing now is dimmed with the reason (`paramInactive`).
  Descriptions hide behind ⓘ unless "Descriptions" is on. A variant shows its file's header line
  (`fileAbout`; factual, no sound claims).
- **Lettering texts** (`*_text`, `side_text_*`): `components/TextField.tsx`, a box that takes
  several lines ("
" in the value) plus Variables (`{tip}`, `{title}`, `{voice}`, ...) with live
  values from the generator's `Text variables:` echo (`parseTextVariables`). `{title}` comes from
  `design_title`, which App sets from the design's name for renders and downloads (not in share links).
- **Customizer**: settings without a section (a file that isn't the generator's) by the file's own
  groups. From OpenSCAD's `.param` export (the rendered file's params
  only); the filter also searches descriptions; hides the "Not yet implemented" group. A string
  param named `*_image` gets `ImagePicker` (scad/art/ SVGs plus the user's own, "Upload SVG…");
  picking one also sets `<name>_aspect`.
- **Readouts**: cards from the render log (`parseSummary`: length/tip/facing/air; the Air card turns the air into mm on the cork vs the voice's preset, src/corkFit.ts, whose `PRESET_AIR` `npm run check` keeps current) and two echo-only
  reports (`facing_report()` -> facing chart + feeler-gauge stops, `clearance_report()` -> thinnest
  wall). Facing has one meaning everywhere: the facing length, tip to the break (the Facing length
  setting, the Facing card, Compare, the check card); the feeler-gauge stops fold under the facing
  chart and are on the check card. The Wall card says "at the rails" beside the window and shows "…"
  until the new model is measured. The full-quality render appends the reports and zoom targets to
  its source (`REPORTS_ECHO`, +~40ms instead of two more runs; their lines are kept out of the
  console); separate runs only when the model on screen came without them (`ensureReports`).
- **Notes** (`Notes` in Readouts.tsx): validate() warnings that need the player in yellow; ones
  about a value adjusted automatically (`isAdjustment`) folded into "Adjusted automatically (n)".
- **Facing chart** (`FacingChart.tsx`, under "Tip & facing"): curve chips (`FACING_CHOICES`: As
  designed / Opens early / Even / Opens late / Radius); its points drag: the tip end =
  `tip_opening`, the flat end = `facing_length`, a point between = `facing_model = "gauge"` with
  `facing_gauge_points` as a *value* (`POINT_VALUES`: kept though not a Customizer param, so it
  works on presets, downloads and shares). The drag preview is the JS `pchip` through the same
  cleaned points as `GAUGE_PTS`.
- **Side section** (`ProfileChart.tsx`, `src/profile.ts`; under "Chamber & baffle" and "Body &
  beak"): the STL on screen cut at x = 0 (segments chained into loops, even-odd fill), true to
  scale, the tip right and the reed side down. "Before the last change" (dashed) is the previous
  final render with other settings (`sig`), reset per design; B dashed blue when its STL is in frame.
  Each also shows a **slice across** it where the slice line is (drag the line, or "Where to slice"):
  the Outside's outline (`crossOutline()`: rays up from the cut's bottom middle, closed along the
  reed side, so the window and bore don't show), the Inside's cut (`crossSection()`), before dashed
  and B; Edit shape dots there add an offset point at the slice. **Slider ends:** every directional slider has words under its ends (`paramEnds`,
  `ENDS` in design.ts, e.g. Crisp / Smooth); measurements (cork diameter) have none.
  **Edit shape** (`src/shapeEdit.ts`): the section's lines (Body & beak: top, underside, width;
  Chamber & baffle: baffle, floor, inside width) from `shape_edit_lines()`, which rides along with
  every full render's reports (`SHAPE_ECHO`, no measurable cost), mapped into the print frame; a few
  dots per line (`LINES`; ends where a line meets another part are pinned) drag up/down and set the
  generator's `*_adjust` offsets (`setPointList`, so undo, shares and downloads carry them). A top
  view for the widths shows while editing. The line previews during a drag; the model follows.
- **Exact points** (the rail's Points; was Curves; `CurveEditor.tsx`, `curves.ts`; the `*_adjust` lists are left out): every single-line top-level `name = [[a, b],
  ...];` in the rendered file, named and grouped by part (`CURVE_GROUPS`; others under "Other"). PCHIP drawn exactly as the generator evaluates it; drag knots, click
  to add, Delete, typed values, Undo; edits are values (`setPointList`), so they work on presets,
  downloads and shares. Dashed = the model's curve from `curve_editor_curves()` (shows where a clamp
  holds a curve back). "Clear" only for overrides; "Reset" drops the value. The svg has
  `touch-action: none` (ignored on svg children).
- **Undo / redo** per design (`hist`): Ctrl+Z / Ctrl+Y outside text boxes, and ↶ ↷; a slider drag is
  one step.
- **Quality** (Draft 32 / Normal 64 / Fine 96 = `render_fn`; only for a file that declares it): a
  change renders once at the chosen quality (a quick Draft pass first was dropped 2026-10-10: it saved
  only ~20%, most of a run being the generator's evaluation, and doubled the wait for the final model). Download re-renders when the model on screen isn't
  at the chosen quality (Normal at least).
- **Share links** (`src/share.ts`): `#d=` + base64url(deflate-raw(JSON {v, file, values,
  source?})); presets carry only changed values, other files their text too. Read at startup, then
  dropped from the URL. The user's own pictures go along only with "Include picture" (`art: {name:
  svg}`); without it a `*_image` using one goes out as `""`. Received pictures are kept like uploads
  (`receiveArt`: a clash gets `_2`). When the clipboard is refused (plain http on the LAN) the link
  shows in a box.
- **Appearance** (`src/appearance.ts`): theme (`<html data-theme>`, CSS variables in styles.css: use
  `--accent-fg` for accent-coloured text and lines, `--overlay` for things over the viewer), model
  colour (a variant shows in its family's colour, `VARIANT_COLORS`, while it is the default Gold;
  `setVariantColor` from App, `useModelColor` in the Viewer), viewer background (the WebGL canvas is transparent over the container's CSS background),
  grid, axes.
- **Phone/tablet** below 1024px (`useMediaQuery`): ☰ menu for file/compare/download actions, viewer
  on top with its tools behind ⋯ and the readouts as one line over it (`ReadoutLine`; a tap opens
  the cards; the generator's notes show at the top of the settings), then the settings. The code
  and the console open from ☰ > Code files, over the settings, with "← Design" back. All panels stay mounted
  (`display: none !important`) so editor state survives; `EditorHandle.refresh()` re-measures
  CodeMirror when shown; 16px inputs (no iOS zoom).

## Viewer

- Z-up, camera kept across re-renders. Floating tools: views 3D / Table / Top / Left / Right / Tip
  (left from +X, right from -X: the player's sides as the lettering names them), Quality, Show ▾
  (Edges, Wireframe, See-through, Ligature, Reed), A/B, a camera icon (PNG of the view).
- **Section view**: lengthwise clips x <= pos (x >= pos after the Right view, `secFlip`, so both
  side views look at the cut), across clips z <= pos; a BackSide flat-coloured cap
  mesh makes cut walls read solid. **See-through** (`applyLook`). Dev-only `window.__viewer` for
  scripted cameras.
- **Zoom to parameter** ("Auto-zoom", persisted): touching a parameter row or picking a Curves list
  uses `param_focus()` (fetched after each final render; a touch uses the latest data at once) and
  the camera flies there (450ms, cancelled by orbiting); parts inside turn the lengthwise section on
  until the next outside part, unless the user chose the section.
- **Ligature**: "Make a ligature for this mouthpiece" sets `ligature_made` (so saves, downloads and
  links keep it). `lig` in the session is only the view: on / beside / hidden ("made · hidden");
  the reed is its own toggle. After each render App runs `ligature_seated` and/or
  `reed_model`, whichever is shown (`loadLigature`); the viewer shows them in A's frame (`lig` graphite,
  `reed` pale; "beside" stands the band in front of A). Readout line from `parseLigature`.
- **Cap**: as the ligature: "Make a cap for this mouthpiece" sets `cap_made`; `capV` (session `cap`) is
  the view: on / beside. After each render App runs `cap_seated` (`loadCap`); the viewer shows
  it see-through teal on A (`capG`) or opaque beside it (+Y). `CapHead`: readout (`parseCap`, warnings),
  Hide / Beside / Download cap STL / Remove; the print kit and Download ▾ take `<name>_cap.stl` when made.
  The Cap section's controls show once made. `part = cap` (an old link) still shows it alone, with
  `PartNote`. Items with `when` in `design.ts` show only for one value of another setting.
- **Part tabs** (no tab bar since layout B: the rail's Ligature and Cap open theirs, every other place
  the mouthpiece's; `partTab` in the session): each
  `DesignSection` has a `tab` (default mouthpiece); other settings hide the other tabs' groups
  (`PART_GROUPS`: Ligature, Cap); a search looks in every tab. Opening a tab sets the view toggles as
  a start (`openPartTab`: the ligature's shows the ligature, not the cap; the cap's shows the cap and the
  printed ligature under it, even before one is made; the mouthpiece's brings the mouthpiece back);
  the toggles change it from there. `showMp` (App) hides the mouthpiece: the view's Show menu
  ("Mouthpiece") or the heads' "Alone"; the viewer's `showModel` then overrides its A/B `showA`, and the
  ghost and the cap's see-through go with it. The tab also picks the Download button (`dlWhat`: the part
  once made) and the readouts (`PartNote` with the part's numbers; the heads show them only on the
  phone). Opening a part tab puts `part` back to the mouthpiece. "What to print" offers the mouthpiece
  and the test ring (an old link's value stays listed).
- **A/B compare**: "Compare with…" (a device STL / .scad, presets, your designs, open files); "Pin
  as B" freezes the current model; dropping an .stl pins it. B snapshots carry the summary and a
  facing report, so the cards show "B …", the facing chart draws B dashed, and the Compare section
  lists the numbers then the parameter diff. A legend chip (✕ clears B), "A"/"B" labels; a new B
  switches to side by side (+X; +Y in left/right views or with a lengthwise cut). View settings
  live in a module-level store (both layouts mount their own viewers), toggles in
  `open-mouthpiece-view-v1`. Phone: a drag bar under the view sets its height (20-85dvh, kept in
  `open-mouthpiece-phone-view-v1`).
- **An STL as B**: `meshFrame.ts` (the browser port of `mesh_frame.mjs`'s `toFrame`: reed table =
  largest flat face with the mesh on one side, long axis, thin end = tip) into the design frame,
  then the model's print rotation (`FRAME_ECHO`), stood on its lowest point. No table found: shown
  as uploaded. Not persisted (too big for localStorage).
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

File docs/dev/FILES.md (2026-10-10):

# What's in the repository

A map of every folder and file, so you can find your way without opening them. Each source file
starts with a comment saying what it does; this page collects those in one place.

## Top level

| Path | What it is |
|---|---|
| `README.md` | What the project is, how to run it, credits, license |
| `CONTRIBUTING.md` | How to work on it: commands, rules, the generator's guarantees, lessons learned |
| `LICENSE` | GPL-3.0 |
| `package.json`, `package-lock.json` | npm scripts and dependencies (React, CodeMirror, three.js, Vite) |
| `index.html` | The page the app is built into |
| `vite.config.ts` | Vite build; also serves `scad/` live as `project/` during `npm run dev` |
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

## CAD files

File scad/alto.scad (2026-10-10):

// Alto saxophone mouthpiece. Values measured from a real alto mouthpiece (0.076" tip):
// rounded, caliper-style dimensions only — no mesh geometry (see Credits in README.md).
// Geometry: lib/mouthpiece_base.scad.

include <lib/mouthpiece_base.scad>  // geometry + defaults; everything below overrides it (keep this line first)

/* [Shank] */
// Your neck cork's diameter (mm), measured with calipers.
neck_cork_diameter = 16.2; // [10:0.05:27]
// How much smaller than your cork the socket is (mm): bigger = tighter. Try 0.1-0.3.
shank_clearance = 0.2; // [0:0.01:0.6]
// How much wider the socket's mouth is, per side (mm), to ease it onto the cork.
shank_bevel = 1.0; // [0:0.1:3]
// How far in the socket's lead-in goes (mm).
shank_bevel_depth = 1.0; // [0.2:0.1:20]
// How far the cork goes in (mm). Other settings give way to keep it.
shank_depth = 22.0; // [10:0.5:70]
// Diameter of the tube behind the socket (mm), about your neck tip's inside diameter.
bore_diameter = 16.2; // [8:0.1:24]
// Angle between the neck's line and the reed table (degrees); about 4 is typical.
bore_tilt = 4.4; // [-3:0.1:8]
// Outside diameter of the shank at the neck end (mm); grows if the wall gets too thin.
shank_diameter = 22; // [14:0.1:32]

/* [Chamber] */
// Cross-section of the chamber after the throat.
chamber_shape = "horseshoe"; // [round, square, horseshoe]
// Width of the chamber after the throat (mm), whatever the throat's width.
chamber_width = 13.8; // [4:0.1:36]
// How gradually the chamber widens after the throat: low = quickly, high = slowly.
chamber_flare = 0.4; // [0.1:0.05:0.9]
// How far the full width runs toward the tip (mm); 40 = as far as it can.
chamber_full_length = 40; // [0:0.5:40]
// Chamber height before the window (mm); 0 = round. More lowers the floor, less raises it.
chamber_height = 0; // [0:0.1:30]
// Floor from throat to window: - drops early (deeper), + stays high (a ramp).
floor_shape = 0; // [-1:0.05:1]
// Where the throat (the narrowest point inside) sits, from the neck end (mm).
throat_position = 43.5; // [20:0.5:90]
// Width of the throat, the narrowest point inside (mm).
throat_width = 14.2; // [5:0.1:24]
// Length of the bore's narrowing into the throat (mm). Short = an abrupt step.
throat_taper = 9; // [1:0.5:80]
// Throat cross-section; "chamber" = the same as the chamber.
throat_shape = "chamber"; // [chamber, round, square, horseshoe]

/* [Baffle] */
// The roof's shape over the reed (see the picture); Original = the preset's own.
baffle_type = "measured"; // [measured, flat, rollover, step, concave]
// Moves the baffle toward the reed (+) or away from it (-) (mm).
baffle_height = 0; // [-3:0.1:4]
// Moves where the baffle begins, toward the tip (+) or the neck (-) (mm).
baffle_start = 0; // [-15:0.5:15]
// Bends the baffle: - comes down early, + stays up and drops late.
baffle_curve = 0; // [-1:0.05:1]
// Height of a smooth hump on the baffle just behind the tip (mm).
baffle_hump = 0; // [0:0.1:3]
// A texture on the baffle: grooves along it, grooves across it, or dimples.
baffle_texture = "none"; // [none, along, across, dimples]
// Texture cut into the baffle (engraved) or standing out of it (raised).
baffle_texture_style = "engraved"; // [engraved, raised]
// How deep the texture cuts, or how far it stands out (mm); less where there is no room.
baffle_texture_depth = 0.4; // [0.1:0.05:1]
// Distance between the grooves or dimples (mm).
baffle_texture_spacing = 3; // [1.5:0.1:8]

/* [Window] */
// Length of the opening under the reed (mm).
window_length = 39.0; // [8:0.5:70]
// Width of the opening under the reed (mm); kept inside the rails automatically.
window_width = 15.1; // [6:0.1:22]
// How much narrower the window is at the back (mm).
window_taper = 3.3; // [0:0.1:12]
// Rounding of the window's back corners (mm).
window_rear_radius = 5.5; // [0:0.1:10]
// Chamber side walls over the window (degrees): + lean out (scooped), - lean in.
sidewall_angle = 0; // [-20:1:30]
// Width of the side rails the reed seals on (mm).
side_rail_width = 1.0; // [0.8:0.05:2.5]
// Thickness of the tip rail (mm).
tip_rail_thickness = 2.0; // [0.3:0.02:3]
// How round the tip is, seen from above: how far back its curve reaches (mm).
tip_curve = 3.5; // [0.5:0.1:12]

/* [Table] */
// Width of the reed seat at the tip (mm). Match your reed.
table_width_tip = 16.8; // [8:0.1:30]
// Width of the reed seat at the back (mm). Match your reed's heel.
table_width_rear = 13.2; // [8:0.1:30]
// From the tip to the table's back end (mm), facing included; longer than the reed is normal.
table_length = 71.8; // [50:0.5:120]
// A slight hollow along the reed seat (mm) so the reed seals at both ends.
table_concavity = 0; // [0:0.005:0.1]

/* [Facing] */
// Gap at the tip, from the tip rail to a straightedge on the table (mm).
tip_opening = 1.93; // [0.5:0.01:4.5]
// From the tip back to the break, where the rails leave the flat table (mm).
facing_length = 23.8; // [10:0.1:45]
// How the facing curves (the chart's buttons set it too): Power curve, Radius or Gauge points.
facing_model = "power"; // [power, arc, gauge]
// For the Power curve: 2 opens evenly; lower opens sooner, higher later.
facing_exponent = 1.8; // [1.5:0.05:3]

/* [Exterior] */
// Total length, neck end to tip (mm). Also changes the inside volume.
overall_length = 89.3; // [55:0.1:160]
// Widest outside width of the body, side to side (mm).
body_width = 29; // [18:0.1:40]
// Height of the body's top above the reed table, at its tallest (mm).
body_height = 27.6; // [18:0.1:40]
// Height of the beak at the tip (mm).
beak_tip_height = 3.6; // [2:0.1:8]
// Body cross-section: 2 = round, higher = boxier, lower = pointed sides.
body_squareness = 2.0; // [1.2:0.1:8]
// The beak's top, seen from the tip: ridged (a peak along it) or flat.
beak_squareness = 1.6; // [1.2:0.1:8]
// The beak's line from the side: full (bulging) or scooped (hollowed).
beak_curve = 0; // [-1:0.05:1]
// Moves the shoulder (the chart's shoulder dot) back for a longer beak, forward for shorter (mm).
beak_length = 0; // [-15:0.5:15]
// 0 = a crisp step (as designed), 1 = a smooth, gradual drop into the beak.
shoulder_smoothness = 0; // [0:0.05:1]
// How wide the beak's top is: - narrower, rounder top; + wider, fuller top. 0 = as designed.
beak_top_width = 0; // [-1:0.05:1]
// How far the shoulder line runs down the sides toward the tip (mm); 0 = straight across.
shoulder_sweep = 0; // [0:0.5:20]
// The lower sides near the tip, seen from the tip: tucked in (curved) or straight down.
underside_squareness = 1.2; // [1.2:0.1:8]
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

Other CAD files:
scad/baritone.scad
scad/soprano.scad
scad/tenor.scad
scad/experiments/dual_reed.scad
scad/extras/c_melody.scad
scad/variants/alto_ash.scad
scad/variants/alto_birch.scad
scad/variants/alto_cedar.scad
scad/variants/alto_flamma.scad
scad/variants/alto_silva.scad
scad/variants/alto_unda.scad
scad/variants/baritone_ash.scad
scad/variants/baritone_birch.scad
scad/variants/baritone_cedar.scad
scad/variants/baritone_flamma.scad
scad/variants/baritone_silva.scad
scad/variants/baritone_unda.scad
scad/variants/soprano_ash.scad
scad/variants/soprano_birch.scad
scad/variants/soprano_cedar.scad
scad/variants/soprano_flamma.scad
scad/variants/soprano_silva.scad
scad/variants/soprano_unda.scad
scad/variants/tenor_ash.scad
scad/variants/tenor_birch.scad
scad/variants/tenor_cedar.scad
scad/variants/tenor_flamma.scad
scad/variants/tenor_silva.scad
scad/variants/tenor_unda.scad

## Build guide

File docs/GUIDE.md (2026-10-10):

# Open Mouthpiece user guide

Open Mouthpiece is a free web app for designing saxophone mouthpieces and 3D printing them. You
pick a soprano, alto, tenor or baritone mouthpiece to start from, adjust things like the tip
opening, facing, baffle and chamber, and download a file to print. Everything happens in your
browser. You don't need an account or any software, and your designs aren't stored on our server.

Open Mouthpiece is AI-generated: the app, the mouthpiece generator and this guide were written by
Claude, Anthropic's AI model, directed by a saxophonist who prints and plays the results.

Open the app at https://opensaxmouthpiece.org.

The app with the section buttons on the left, the settings panel, and the mouthpiece in the 3D view

**Contents**

1. [Getting started](#1-getting-started)
2. [The screen](#2-the-screen)
3. [Choosing a starting point](#3-choosing-a-starting-point)
4. [Changing settings](#4-changing-settings)
5. [What each section covers](#5-what-each-section-covers)
6. [Shape charts](#6-shape-charts)
7. [Readouts](#7-readouts)
8. [The 3D view](#8-the-3d-view)
9. [Comparing designs](#9-comparing-designs)
10. [Ligature and cap](#10-ligature-and-cap)
11. [Saving, opening and sharing](#11-saving-opening-and-sharing)
12. [Downloading and printing](#12-downloading-and-printing)
13. [Phones and tablets](#13-phones-and-tablets)
14. [Using OpenSCAD](#14-using-openscad)
15. [App settings and privacy](#15-app-settings-and-privacy)
16. [Troubleshooting](#16-troubleshooting)
17. [Other documents](#17-other-documents)

## 1. Getting started

1. Open the app. The alto mouthpiece loads first.
2. Choose your saxophone in the list at the top left (Soprano, Alto, Tenor or Baritone).
3. Click **Fit** on the left and enter the diameter of your neck cork. If you don't know it, leave
   the default, which suits most necks.
4. Make your changes. **Tip** has the tip opening and facing, **Chamber** has the inside and
   **Body** has the outside. The model updates a few seconds after each change.
5. Before printing the whole mouthpiece, print a shank test ring to check the fit on your cork.
   Click the small arrow next to the yellow Download button and choose **Shank test ring**. It only
   takes a few minutes to print.
6. Click **Download mouthpiece STL** to get the file for your printer. It's already oriented for
   printing.
7. Click **Save as…** to keep your design.

The [printing guide](PRINTING.md) covers the rest: printer settings, sanding the table and facing,
checking the print, and making changes after you've played it.

## 2. The screen

On a computer, the app has four areas.

The **top bar** has the design list, **Save as…** and **Open…** on the left. On the right are
**Support**, **Share**, the **Download** button with its arrow menu, **More** and the **⚙**
settings.

The **icon bar** down the left side opens each group of settings: Tip, Fit, Chamber, Body and
Personalize for the mouthpiece, then Ligature, Cap and Print. Compare, Points, Code and About are
at the bottom. A dot or number on a button means you've changed something in that group.

The **settings panel** next to it shows the measurements at the top and the settings for the group
you picked below them.

The **3D view** shows the mouthpiece. The view controls are along its top, and the **Shape charts**
button is at the bottom left.

When you open a group of settings, the view turns to the part of the mouthpiece those settings
change. You can drag the borders between the columns to resize them.

## 3. Choosing a starting point

The list at the top left contains:

- The four standard mouthpieces: soprano, alto, tenor and baritone. These are based on
  measurements of well-known 3D-printed mouthpieces (see the credits in About). The alto, tenor
  and baritone versions have been printed and played.
- Three variations of each, called Flamma, Silva and Unda. Each one changes several settings at
  once and adds some lettering and decoration as an example. A short note above the settings
  explains how it differs from the standard version.
- A C-melody mouthpiece, under Extras.
- Your own saved designs.
- Any .scad files you've opened.

You can't overwrite the built-in designs, but you can change them as much as you like and then
use **Save as…** to keep your version under a new name. If "(edited)" appears after the name, the
design has changes that haven't been saved.

## 4. Changing settings

Each setting has a slider and a box where you can type an exact number. The words under each end of
the slider tell you what that direction does, such as Closed and Open or Short and Long. A short
description under each setting gives the unit. If you'd rather not see the descriptions, turn
them off under **Options**.

The longer sections are split into small groups, one per part (for example Baffle, Chamber,
Throat and Window), each under a small heading. A group shows its main settings first. Click
**More** under it to see the rest of that group's settings. A group with nothing but smaller
settings, like Table, shows only its own button. Settings that only matter after you pick
something, such as a texture's depth, appear right under it once you do.

To find a particular setting, type part of its name in the **Find a setting** box, for example
"baffle" or "window".

Use the ↶ and ↷ buttons (or Ctrl+Z and Ctrl+Y) to undo and redo. **Reset** takes the design back
to how it was when you opened or last saved it, and the number on the button shows how many
settings you've changed.

Two more options are in the **Options** menu. **Auto-zoom** moves the view to whatever part a
setting affects, and cuts the model open for parts on the inside. Turn it off if you'd rather the
view stayed put. **Compare with the original** puts the unchanged design next to yours.

The app won't let you make a mouthpiece that can't be printed. If a setting would make a wall too
thin, the app limits it and a note under the measurements tells you.

## 5. What each section covers

For a full list of settings with before-and-after pictures, see [Every setting](PARAMETERS.md).
The [glossary](GLOSSARY.md) explains the parts of a mouthpiece and which settings change each one.

**Tip & facing.** *Tip opening & facing*: the tip opening is in thousandths of an inch, but you
can type a value in mm too. The facing length is measured from the tip back to the break, where the
rails leave the flat table; its More has the shape of the facing curve. *Rails*: the thickness of
the tip rail and the width of the side rails, with the roundness of the tip under More. *Table*:
the table's length, width and hollow.

**Fit on the horn.** Enter your neck cork's diameter here, and set the cork squeeze, which is how
much smaller the socket is than the cork. A bigger number gives a tighter fit, and 0.1 to 0.3 mm is
typical. You can also set how far the cork goes in, and download a shank test ring. Under More
settings are the bevel at the opening of the socket, the bore size and the angle of the table.

**Chamber & baffle.** The inside of the mouthpiece, in four groups. *Baffle*: its shape, height and
hump, and a texture on it (grooves along it, grooves across it, or dimples, engraved or raised, with
their depth and spacing); More has where the baffle starts and how it curves. *Chamber*: its shape
(round, square or horseshoe) and width; More has its height and floor, how it widens past the
throat and the angle of its side walls. *Throat*: its width; More has its position, the narrowing
into it and its shape. *Window*: its width; More has its length and corners.

**Body & beak.** The outside, in three groups. *Size*: overall length and the width and height of
the body, with the shank's outside diameter under More. *Beak*: its height at the tip, curve,
length and top. *Shoulder & sides*: the shoulder and the sides near the table, with the shoulder
sweep and the body's cross-section under More.

**Personalize.** Add text and a picture *On top*, text on the *Sides*, and text around the *Shank
band*, where you can also add rings, flutes, a spiral or knurling. You can use one of the built-in
pictures or upload your own SVG file. Click **Variables** next to a text box to insert values from
the design, such as the tip opening (`{tip}`) or the design's name (`{title}`). Text can run over
several lines. The same font is used for all text (*All lettering*) unless you choose a different
one for a particular text under its group's More. Text on the mouthpiece is always engraved so the
ligature can't catch on it.

**Ligature and Cap.** Their settings come in groups too: the ligature's *Band*, *Fit* and *Text &
picture*; the cap's *Goes over*, *Fit & slot*, *Shape*, *Air holes & vents* and *Text & picture*.

**Print.** Choose whether to print the mouthpiece or a shank test ring. **Extra to sand off** adds
a little material to the table and facing so you can sand them flat after printing (the printing
guide explains when to use it). You can also download the print kit here. Under More settings are
the minimum wall thickness, the smoothness of the model, and the print orientation.

## 6. Shape charts

The Outside chart in Edit shape mode, with dots on the side view, a cross-section, and the view from above

Click **Shape charts** at the bottom left of the 3D view to open a panel with three charts. Use
**Larger** and **Smaller** to resize it.

**Facing curve** shows the gap between the reed and the rails from the tip back to the break. You
can pick a ready-made curve (As designed, Opens early, Even, Opens late or Radius), or drag the
points yourself. The point at the tip sets the tip opening and the point at the flat end sets the
facing length. Click on the curve to add a point and double-click a point to remove it. Open
**Feeler gauge stops** to see where standard feeler gauges should stop, which is useful for
checking a print.

**Outside** shows the mouthpiece from the side and a cross-section of it. To move the
cross-section, drag the line on the side view or use the **Where to slice** slider.

**Inside** works the same way for the inside of the mouthpiece, showing the baffle and floor from
the side and the inside width in the cross-section.

To change the shape directly, click **Edit shape** on the Outside or Inside chart and drag the
dots. On the outside you can change the top, the underside and the width. On the inside you can
change the baffle, the floor and the inside width. The change in mm is shown while you drag. Use
**Undo** to step back, **Reset shape** to remove all your shape changes, and **Done** when you're
finished. Shape changes are saved and shared along with the rest of the design.

For finer control, **Points** in the icon bar lets you edit the exact points of every curve in the
design. You won't need it for normal use.

## 7. Readouts

The boxes at the top of the settings panel show:

- **Tip**: the tip opening.
- **Facing**: the facing length.
- **Length**: the overall length.
- **Air**: the volume of air inside the mouthpiece, from the end of the neck to the tip. This
  affects how far onto the cork you'll need to push the mouthpiece to play in tune, so it's
  compared with the standard design for your saxophone.
- **Wall**: the thinnest wall, and where it is.

Click the readouts for more detail. Any notes about your design appear underneath them.

## 8. The 3D view

Drag to rotate the model, scroll or pinch to zoom, and right-drag or use two fingers to move it.

The buttons along the top of the view do the following:

- **3D, Table, Top, Left, Right** and **Tip** switch to a standard view.
- **Show** lets you turn edges, wireframe and see-through on or off, and choose which parts are
  visible. When **Ghost after a change** is on (it starts off), the previous shape shows faintly for a moment
  after each change.
- **Last shape** shows the previous shape again, until you turn it off.
- **Cut open** cuts the model in half lengthwise or crosswise, so you can see inside.
- **Quality** sets how detailed the preview is. Draft is the fastest. Downloads are always full
  quality.
- The camera button saves the current view as a picture.

If the view has zoomed in on one part, click **Whole model** at the bottom right to see all of it.

## 9. Comparing designs

Click **Compare** in the icon bar to show a second design (B) next to the one you're working on
(A). There are a few ways to choose B:

- **Pin this model as B** keeps a copy of your design as it is now, so you can make changes and
  see the difference.
- **Compare with the original** uses the design as it was before your changes.
- **Compare with…** lets you choose any built-in or saved design, a .scad file, or an STL file of a
  mouthpiece you already own. You can also drag an STL file onto the page.

You can show the two designs side by side or overlapping. The measurements show both designs'
numbers, the facing chart shows B's curve as a dashed line, and the Compare panel lists every
setting that's different. Click **← B** next to a setting to copy B's value into your design.

A variant next to the standard alto, with the list of settings that differ

## 10. Ligature and cap

A mouthpiece with a reed, a printed ligature and a see-through cap

The app can make a ligature and a cap that fit your mouthpiece.

To make a ligature, click **Ligature** in the icon bar, then **Make a ligature for this
mouthpiece**. It's a ring that's shaped to the mouthpiece, so it still fits after you make
changes. It slides on over the tip and holds the reed in place by friction. You can adjust its
shape, thickness, how tightly it grips the reed, its length and position, and add text or a picture.
Both start with the same picture as the mouthpiece, if it has one; you can choose another or none.

To make a cap, click **Cap**, then **Make a cap for this mouthpiece**. The cap fits over the tip,
the reed and the ligature. It can be made to fit the printed ligature or a metal one (you enter
the metal ligature's measurements). It has a slot, side vents and air holes in the end so the reed can dry, and clips onto
the ligature.

Each one has its own download button. You can also show it beside the mouthpiece, hide it, or
remove it. Once you've made them, they're saved and shared with your design, and the ligature is
included in the print kit. See the [printing guide](PRINTING.md#4b-a-ligature-made-for-it-optional)
for how to print and fit them.

## 11. Saving, opening and sharing

**Save as…** keeps a copy of the design under a new name in the app, under Your designs. It only
exists in this browser on this device, so it will be lost if you clear your browser data or switch
browsers. To really keep a design, download its design file (.scad) from **Download ▾** (next
section): it opens again in the app with **Open…**, or in OpenSCAD.

To open a saved design file, click **Open…** or drag the file onto the page.

**Share** copies a link to your design. Anyone who opens the link sees your design. The design is
stored inside the link itself, so nothing is uploaded. If you've added your own picture, you can
choose whether to include it.

## 12. Downloading and printing

The yellow **Download** button downloads the part you're working on: the mouthpiece, or the
ligature or cap when you're in their section. The arrow next to it lets you tick what to download,
then **Download**:

- **Mouthpiece STL**, oriented for printing.
- **Shank test rings** at three cork squeezes (0.10, 0.20 and 0.30 mm), to check the fit first.
- **Ligature STL** and **Cap STL**, if you made them.
- **Design file (.scad)**, the safest way to keep a design: it opens again with **Open…** or in
  OpenSCAD, and holds the ligature and cap too. A picture comes beside it in an `art` folder.
- **Check card**, the numbers to measure the print against.
- Under **More formats**, a settings-only .scad file: much smaller, but it only opens in this app.

More than one file comes as one zip. **Tick all** ticks everything (the print kit). Your ticks are
remembered.

The [printing guide](PRINTING.md) explains how to print the mouthpiece, check the fit, finish the
table and facing, and test it.

## 13. Phones and tablets

The app works on phones and tablets, with a few differences:

- The groups of settings are in a bar at the bottom of the screen, and the settings appear below
  the 3D view.
- The measurements are shown in one line above the view. Tap it to see the details.
- The **☰** menu at the top left has downloads, quality, saving, opening, sharing, comparing,
  appearance, the code editor and About.
- The **⋯** button in the view has the view buttons and Cut open.
- The shape charts appear inside each group of settings.

Updates take longer on a phone than on a computer. Setting the quality to Draft makes them faster.

The app on a phone

## 14. Using OpenSCAD

The mouthpiece is made by an OpenSCAD program. Click **Code** in the icon bar to see the program
and OpenSCAD's messages. You can edit the code of your own designs and the model will update.
The built-in designs are read-only. A downloaded design file also opens in OpenSCAD on your
computer, where the settings appear in the Customizer. To make the ligature or cap there, set
**part** (in the Output tab) to `ligature` or `cap`. The source code for the whole project is on
[GitHub](https://github.com/OpenSaxMouthpiece/open-mouthpiece).

## 15. App settings and privacy

The **⚙** menu at the top right lets you change the theme (light, dark or your system's setting),
the colour of the model, the background, and whether the grid and axes are shown. With the
default Gold, the variants show in their own colours: Flamma orange, Silva green, Unda blue.

Your designs stay in your browser unless you download or share them. The app sends anonymous
usage information to help us improve it, such as which designs and settings are used and whether
anything goes wrong. It never sends your text, pictures or file names, doesn't use cookies, doesn't
record IP addresses, and can't connect one visit to another. You can turn this off with **Share
anonymous usage** in the **⚙** menu.

## 16. Troubleshooting

**The model is slow to update.** The app rebuilds the whole mouthpiece after every change, which
takes a few seconds on a computer and longer on a phone. Set the quality to Draft while you're
experimenting. Text and shank decorations add a little extra time.

**A setting doesn't change anything.** Some settings only work together with another one. For
example, the chamber's widening only applies when the chamber is wider than the throat. These
settings are greyed out with a note explaining why. A setting may also be limited to keep the walls
thick enough to print, in which case a note appears under the measurements.

**The model looks like it has a hole in it.** In the default view you can often see inside the
mouthpiece through the window. Switch to the Left view or use Cut open to check.

**My saved design has disappeared.** Designs saved in the browser only exist in that browser on
that device, and are deleted if you clear your browser data or use private browsing. To keep a
design safe, download it as a design file (.scad).

**My picture doesn't appear.** Pictures need to be SVG files with solid shapes. Thin line drawings
won't work. If part of the picture is cut off, you'll see a warning; try making it smaller or
moving it.

**The mouthpiece doesn't fit my cork.** Print test rings at a few different squeezes (the print
kit includes three). If none of them fit, measure your cork with calipers in two directions and
enter the new diameter. See step 1 of the
[printing guide](PRINTING.md#1-check-the-cork-fit-15-minutes).

**I found a problem or have a suggestion.** Please let us know on
[GitHub](https://github.com/OpenSaxMouthpiece/open-mouthpiece/issues).

## 17. Other documents

- [Printing guide](PRINTING.md): printing, finishing, checking and play-testing.
- [Glossary](GLOSSARY.md): the parts of a mouthpiece, with diagrams.
- [Every setting](PARAMETERS.md): each setting, with pictures.
- [Hosting the app](HOSTING.md) and [contributing to the project](../CONTRIBUTING.md).

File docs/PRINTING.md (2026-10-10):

# Test-printing a mouthpiece

A first print answers the questions no measurement can: does it fit the neck, does the facing come
out accurate, and how does it play. This is the order that wastes the least plastic.

Everything happens in the app (https://opensaxmouthpiece.org/): design your mouthpiece, then
download its STL. The buttons down the left (along the bottom on a phone) open each section:
the mouthpiece's (Tip, Fit, Chamber, Body, Personalize), then **Ligature**, **Cap** and **Print**.
The Download button saves the part you're working on; its **▾** lists everything else to download.
**Print**'s **What to print** picks the mouthpiece or a shank test ring. Every download is already
oriented for printing.

Or take everything at once: **Download print kit** (in Print; or Download ▾, Tick all) makes one zip with
the mouthpiece, the three shank test rings below, the ligature and cap if you made them, the design
file, and a check card with the numbers to measure the print against (tip opening, facing stops).

## 1. Check the cork fit (15 minutes)

Print three shank test rings (the print kit has them): set **What to print** to *Shank test ring*,
then download one at each **Cork squeeze** (Fit on the horn) of 0.10, 0.20 and 0.30 mm. Each is the
socket end of the mouthpiece, with a socket that much smaller than the cork, so a bigger number is
a tighter fit. **Mark each one with a pen as it comes off the plate**, since they look alike.

Try them on your neck cork (lightly greased, as usual):

- Too tight to push on: too much squeeze (try a smaller one).
- Slides on with a firm, even push and doesn't wobble: that's yours.
- Wobbles or feels loose: not enough squeeze (try a bigger one).

Set **Cork squeeze** to the one that fit. If none fits, measure your cork with calipers in two
directions (corks are often slightly oval), set the cork diameter and print the rings again.

The socket's mouth has a bevel so it doesn't catch on the cork (Fit on the horn -> More:
**Lead-in at the opening** and **Lead-in length**, 1 mm each). A bevel much wider than it is long
gets hard to print without supports.

## 2. Print the mouthpiece

Set **What to print** back to *Mouthpiece*. Two ways to print it (Print -> **Extra to sand off**):

- **0 (as designed):** try this first if your printer is accurate (resin, or a well-tuned FDM
  printer at fine layers).
- **0.15 mm:** extra on the reed table and facing, to sand flat (step 3). Use this if prints from
  your printer come out slightly warped or rough.

Suggested settings (a starting point, not gospel):

| | FDM (filament) | Resin (MSLA) |
|---|---|---|
| Orientation | as exported: standing on the neck end | as exported, or tilted slightly; supports only on the neck end face |
| Layer height | 0.08–0.12 mm | 0.03–0.05 mm |
| Walls / infill | solid: 100% infill, or 6+ perimeters | solid (no hollowing) |
| Supports | none needed (see below) | on the neck end face only |
| Seam | down one side, never on the table, rails or beak | — |
| Material | PETG or PLA for testing | a tough, food-contact / biocompatible resin |

**Supports:** measured on the presets, surfaces steeper than 45° are under 0.5% of each
mouthpiece: the tip rail bridging over the window at the very top, a small ledge at the beak
shoulder on the tenor, and a few mm² inside the bore. Your slicer may flag them, but they print
fine without supports, and supports inside the bore would be hard to remove. Lettering and pictures are cut slanting toward the shank, so they need none either.

**A word on materials:** this is something you'll put in your mouth, and most printing materials
aren't certified food safe. Even a food-safe filament can collect bacteria in the tiny gaps between
layers. PETG or a biocompatible resin is a good choice, but whatever you use is your call and at
your own risk. Wash it before you play, keep it clean, and reprint it when it starts to look worn.

## 3. Finish the table and facing

The reed must seal on a flat table and even rails. Check the table on a flat glass plate: no
rocking, and no light under it when you look along it.

If you printed the stock version, or the table isn't flat:

1. Tape wet-and-dry paper (400 grit, then 600, then 1000) to glass or a stone countertop.
2. **Table:** hold the mouthpiece flat, table down, and sand with light strokes along its length,
   turning it around every few strokes, until the table is evenly matte right to its edges. On
   the stock version, that's about when the extra 0.15 mm is gone.
3. **Facing (the curved part of the rails and the tip):** carefully. Roll the mouthpiece from the
   table up onto the tip in one smooth motion, pressing lightly and evenly on both rails. A few
   passes, then check (step 4). Uneven rails leak air and make it stuffy or squeaky, so it's
   better to stop early than to overdo it.

Sanding changes the facing. If you can't get it right, the as-designed print (no stock) is the
fairer test of the design.

## 4. Check it against the design

The app's readouts give the targets:

- **Tip opening:** the readout's tip opening, in mm and thousandths of an inch.
- **Facing:** **Shape charts** (under the view) -> **Facing curve** -> **Feeler gauge stops** lists
  where standard feeler gauges should stop along the facing, if you want to check a print against it.
- **Air volume:** the air between the end of the neck and the tip. It stands in for the missing
  tip of the horn's cone, so it mostly decides where the mouthpiece plays in tune on the cork: more
  air, further on; less air, further out. There is no single right number (makers make smaller
  chambers longer to land on the same spot), so the readout compares yours with the preset's, e.g.
  "about 3 mm further onto the cork than the Alto preset". Change it by the size of the chamber or
  the baffle, or by the socket's depth. If you know your current mouthpiece's volume (fill it with
  water, the window taped shut, minus what the neck fills), a similar volume sits at a similar spot.
  The air also sets how wide the octaves are
  ([saxophone acoustics, UNSW](https://www.phys.unsw.edu.au/jw/saxacoustics.html)).

## 4b. A ligature made for it (optional)

Store-bought ligatures fit only mouthpieces close to the one they were made for. The app can make
one from your design: **Ligature** -> **Make a ligature for this mouthpiece**. It shows in grey on the
mouthpiece; **Download ligature STL** gives the print. It's a ring, round over the top and shaped
to the reed underneath, with a longer side (the tab) on top, toward the shank. The **reed** is
the tight spot: it squeezes the reed 0.2 mm (**Reed grip**) and keeps a hair of gap to the body.

- **Print** it standing on its flat front edge, tab up (as downloaded), no supports. PETG or another material
  that flexes a little is better than PLA, which can crack when it's pushed tight.
- **Fit:** put the reed on, slide the ligature on over the tip until it touches the reed, then push
  it back the last mm or so (the app says how far) so it grips. It's a taper fit, like a cork.
- **Any reed fits:** it's a taper fit, so a thicker reed seats it a little further forward and a
  thinner one further back (the app says how far 0.1 mm of reed moves it).
- **Reed not held** (it moves or buzzes): raise **Reed grip** (try 0.3). **Stops too far forward**
  (over the window): lower it. Printing grips of 0.1, 0.2 and 0.3 side by side is a quick way to
  find yours.
- **Thickness**, **Band length**, **Tail toward the shank** and **Position** change how stiff it is and how much of the reed it holds,
  and where; **Shape** can also be fully round or follow the whole mouthpiece.
- **Text on the ligature** / **Picture on the ligature** put lettering or a picture on its top, in
  the font, style (engraved or raised) and depth set under Personalize. The picture starts as the
  mouthpiece's own (**Same as the mouthpiece**); pick another, or none. Keep it short: the band's
  top is only about as long as the band plus the tab.

## 4c. A cap made for it (optional)

A cap keeps the tip and reed safe in a bag. **Cap** -> **Make a cap for this mouthpiece** builds one
around your mouthpiece, reed and ligature, shown see-through (teal) on the mouthpiece; **Download
cap STL** gives the print. Like a store-bought cap it is one smooth shell, tapering from its rim to
a rounded tip, with a slot up from the rim and vents in the sides and the end so the reed can dry; it slides
on over the tip and the rim clips onto the ligature.

- **Print** it standing on its rim, open end down (as downloaded), no supports. The closed end is
  always at least a low dome (**End shape**), because a flat end would be a ceiling printed over air,
  and the **Rim bead** around the open end slopes back at 45° so it needs no support either.
- **Goes over:** the ligature made here (**Ligature**) or a metal one. As on
  store-bought caps, a metal ligature's screws ride in the slot: it starts at the rim as a window as
  wide as the screws, so the cap needn't be big enough to cover them. Give the band's length,
  position and thickness and the screws' width and length, and set **Slot side** to the side
  they're on: under the reed (a standard ligature) or on top (an inverted one).
- **Air:** the **slot**, the **side vents** (slots or round holes, on both sides between the rim and
  the tip) and the **air holes in the end** let air through, so a wet reed dries instead of staying
  damp in a closed cap. The vents print without supports, standing on the rim.
- **Grip:** the rim clips onto the ligature's band; **Grip squeeze** sets how hard. Too loose: raise
  it (try 0.2-0.3); too tight: lower it, or make the slot longer so the rim flexes more. Printing
  0.1, 0.2 and 0.3 side by side finds yours.
- **Any reed fits:** the cap leaves room for a reed up to 4 mm thick and a little wider than the table.
- **Wall**, **Shape** (follows the mouthpiece, or round), **Space at the end** and **End shape**
  change how it looks and how it sits in the hand. **Text on the cap** and **Picture on the cap**
  work like the ligature's (the picture starts as the mouthpiece's).

## 5. Play-test and adjust

Play it next to your usual mouthpiece, with the same reed. Notice where it sits on the cork to play
in tune (a tuner at A = 440). Then change one thing at a time:

| What you hear or feel | Try |
|---|---|
| Too bright, harsh, edgy | lower `baffle_height` (negative), a positive `baffle_curve`, or a wider `chamber_width` / positive `sidewall_angle` |
| Too dark, dull, doesn't project | raise `baffle_height`, add `baffle_hump`, or a negative `baffle_curve` |
| Stuffy, resistant | wider `throat_width`; check the facing for leaks first |
| Too free, spread, hard to control | a slightly smaller `tip_opening` or a shorter `facing_length` |
| Low notes hard to get out | a longer `facing_length`; check the rails seal (step 4) |
| Squeaks, reed chirps | the facing is uneven: check both rails; then `tip_rail_thickness` |
| Plays flat: pushed far onto the cork | less inside air (smaller chamber, or raise the baffle) |
| Plays sharp: pulled far out | more inside air (bigger chamber, or lower the baffle) |
| Upper register sharp when the low one is in tune (octaves wide) | more inside air, or a softer reed |
| Upper register flat when the low one is in tune (octaves narrow) | less inside air, or a harder reed |
| Wobbles on the neck | re-do step 1 |

After each change, compare the new version against the one you played: **Compare** -> **Pin this
model as B** before changing it, then look at the readouts (the air volume row), the shape charts
and the view cut open (**Cut open**).

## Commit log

2026-10-01 Open Mouthpiece: parametric saxophone mouthpiece generator
    OpenSCAD generator plus a browser app (editor, Customizer, 3D viewer)
    running OpenSCAD in WebAssembly. GPL-3.0-or-later.
    [alto.scad, alto_ash.scad, alto_birch.scad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]
2026-10-02 Settings: picture names as labels (Happy face), baffle shape description no longer repeats its options
    [alto.scad, alto_ash.scad, alto_birch.scad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]
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2026-10-02 Accurate sax terms: gauge facing length, wall at the rails, no feel words
    - Facing readout = where a .0015" feeler stops (as refacers quote it); the
    slider is "Facing curve length" (to the break)
    - Tip opening: tip rail to a straightedge on the table, not "to the reed"
    - Facing chips: Opens early / Even / Opens late / Radius (were Free/Focused)
    - Thinnest wall says "at the rails" beside the window, with distance from tip
    - Variants: tone claims removed; the app shows each one's factual summary
    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
    [alto.scad, alto_ash.scad, alto_birch.scad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]
2026-10-02 Tenor preset wholly from the Tenor_64 (no "72" outline left)
    The outline (width, top, underside, widest point) is measured from the
    Tenor_64 in coarse stations, plus its length (96.7), beak tip, window,
    tip rail, table widths, reed length, chamber width and where the baffle
    starts. Baffle, tip, facing, bore and throat were already the 64's.
    IoU vs Tenor_64 0.879 -> 0.907; air 10.5 -> 10.2 cm3. Tenor variants
    regenerated. The "72" tenor credit is removed from the site and README.
    [tenor.scad, tenor_ash.scad, tenor_birch.scad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]
2026-10-02 Print kit download, text and pictures on the ligature, Auto-zoom
    - "Download print kit (.zip)" (Printing section, More, phone menu): the
    mouthpiece, shank test rings at cork squeeze 0.10/0.20/0.30 (plus the
    design's own), the ligature if made, and a check card with the numbers
    to measure the print against (tip, facing, feeler-gauge stops, socket,
    air, thinnest wall).
    - Ligature lettering: ligature_text / ligature_image on the band's top,
    in the mouthpiece's font, style and depth, cut in a skin that follows
    the band. Genus 1 on every voice, shape, tongue side and style; the
    plain band is unchanged (baselines unchanged; sweep 876 samples, 0 failing).
    - "Zoom" is now "Auto-zoom",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
    [alto.scad, alto_ash.scad, alto_birch.scad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]
2026-10-02 Don't close the only design: the app stuck on "Loading…"
    Closing the design on screen when no other design was open left nothing
    to render (only the generator, or no tab). Its tab now has no close
    button; your own design's Close in the top bar opens the default preset
    after it, as Delete does.
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2026-10-02 Anonymous usage (opt-out), no New scratch file, own designs close from their tab
    - src/usage.ts: anonymous events (visit, design opened, setting names,
    sections, features, quality, downloads with the design's numbers),
    batched to the Worker's /api/usage and stored in a D1 database with
    the error reports (worker/usage.sql). Never lettering, pictures, file
    names; no IP, no cookie, nothing links visits. One switch in the gear
    menu, "Share anonymous usage" (the error reports' pref). Read it with
    node scripts/usage.mjs. The Worker drops events until the database
    is bound.
    - No "New" scratch file (a cube meant nothing here; Save as makes a
    new design).
    - Your own or an unsaved desi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
2026-10-05 Mouthpiece cap: made and shown like the ligature
    A cap built from the mouthpiece's own shape: one smooth shell over the tip,
    reed and ligature (printed or metal), a slot from the rim on the screw side,
    air holes in the end, optional side vents, ribs and lettering.
    [alto.scad, alto_ash.scad, alto_birch.scad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]
2026-10-05 C-melody draft preset in a new Extras group
    The alto and tenor presets blended by pitch (scripts/blend_voices.mjs),
    listed under Extras in the pickers and covered by npm run check.
    [c_melody.scad]
2026-10-05 Part tabs; simpler cap and ligature settings
    The settings come in Mouthpiece / Ligature / Cap tabs, each with its own
    view, download and readouts. The ligature and cap work with any reed, and
    the cap keeps only the settings that matter. The mouthpiece can be hidden
    to see the ligature or cap alone.
    [alto.scad, alto_ash.scad, alto_birch.scad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]
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2026-10-05 Settings: dim what your own curves replace; Curves picker in words; min_airgap hidden
    [alto.scad, alto_ash.scad, alto_birch.scad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]
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2026-10-06 Lettering: several lines, variables (tip, title, voice), faster; tip label on the presets
    The side text now sits just behind the ligature by default. Ligature position
    reaches further back (the reed sets the limit, with a note).
    [alto.scad, alto_ash.scad, alto_birch.scad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]
2026-10-06 Mouthpiece lettering is always engraved (raised stays for the ligature and cap)
    [alto.scad, alto_ash.scad, alto_birch.scad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]
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2026-10-06 UI pass: one facing length, Download menu, side section, phone layout
    - Facing means the facing length (tip to the break) everywhere; feeler
    stops fold under the facing chart
    - Download ▾ lists the mouthpiece, a shank test ring, ligature, cap,
    print kit and the design file
    - A side section chart under Chamber & baffle and Body & beak, with the
    shape before the last change dashed
    - The Right view shows a lengthwise cut too
    - "(edited)" in the picker for unsaved settings
    - Phone: readouts as one line over the view, code and console from the
    menu, a shorter welcome hint
2026-10-06 Generator: shape edits as offsets after the sliders (outline, baffle, floor, inside width)
    [alto.scad, alto_ash.scad, alto_birch.scad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]
2026-10-06 Shoulder smoothness: from a crisp step to a smooth drop; pushing the shoulder dot down softens it
    [alto.scad, alto_ash.scad, alto_birch.scad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]
2026-10-06 Intuitive Body & beak: words under every slider's ends, Beak top width, a From the tip view
    [alto.scad, alto_ash.scad, alto_birch.scad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]
2026-10-06 Settings read by what you see: plainer names and end words in every section, a shank picture, a clearer More
    [alto.scad, alto_ash.scad, alto_birch.scad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]
2026-10-06 Personalise: a font per text, text around the shank, shank rings or flutes
    [alto.scad, alto_ash.scad, alto_birch.scad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]
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2026-10-08 Plainer words: section subtitles, a test ring link under the fit, Download says what it saves; focus rings and slider names
    [alto.scad, alto_ash.scad, alto_birch.scad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]
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2026-10-08 Shape edits follow the drag and say when a dot is at its limit; steadier charts; compare in plain words; phone fixes
    [alto.scad, alto_ash.scad, alto_birch.scad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]
2026-10-08 Personalize; shank rings and flutes raised or cut in, down to the end; shape charts in a card over the view
    [alto.scad, alto_ash.scad, alto_birch.scad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]
2026-10-08 Clearer settings and charts: baffle pictures, text direction buttons, reed side on the charts, the ligature and cap back after a reload
    [alto.scad, alto_ash.scad, alto_birch.scad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]
2026-10-08 Shank decoration: rounded rings, V flutes, a spiral and knurling; one ring is How many = 1
    [alto.scad, alto_ash.scad, alto_birch.scad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]
2026-10-08 Body texture: ribs, rings, knurling or dimples all round the body, the table and beak left smooth
    [alto.scad, alto_ash.scad, alto_birch.scad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]
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2026-10-08 Variants: settings only, with shank decorations
    Ash, Birch and Cedar keep their preset's outline and differ only by
    settings the app shows (sliders, choices, text), so each can be rebuilt
    or taken further in the app. Ash gets scooped sidewalls, a smooth full
    beak and shank rings; Birch a crisp set-back shoulder, flat beak top and
    flutes (soprano: knurling); Cedar a scooped beak and a spiral.
    [alto_ash.scad, alto_birch.scad, alto_cedar.scad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]
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2026-10-09 Shape card: Undo and Reset shape; shape edits counted on the rail and section badges
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2026-10-09 Variants: picture and side text centred between the shank and the shoulder; Silva baffle grooves, Unda dimples and a raised spiral; textures skip faint dents
    [alto_flamma.scad, alto_silva.scad, alto_unda.scad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]
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2026-10-10 Downloads: a Save button when the browser won't start a file after a long wait; the print kit includes the design file
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2026-10-10 Chamber wider than the window: walls lean out from the rails instead of a shelf, and the wall fit is smoothed along the window (fixes #1 rough inside edges)
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2026-10-16 Faster print kit and render start
    Kit files are made side by side, reused where current; shorter wait before a render starts.
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2026-10-17 Old design files open unchanged; readouts get the generator's report again
    An older file's window_width / window_taper lines are rewritten as its rails when it opens, so it
    no longer shows as edited (its window stays the same); a link's values still become rails
    settings. The REPORT line was stripped from the log the readouts read whenever they were on
    screen, which hid the asked-vs-got notes and the window controls' numbers: it now stays in the
    log and only the console leaves it out.
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2026-10-17 Docs: measuring feeler stops for a copy, in step with the typed-in stops
    MATCHING.md: measure each feeler stop in mm from the tip, type them into the facing chart's
    Feeler gauge stops (any order), a note on glass gauges whose scale shows twice the distance,
    and why the Facing readout comes out a little longer than the 0.0015" stop (the break is where
    the gap reaches zero). The worksheet lists all five stops. facing_length: the 0.0015" feeler
    stops just short of the break, not at it (as the print kit already says).
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2026-10-18 Ligature: room for the plate is a setting (default 1.8mm, looser than before)
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2026-10-18 Ligature: 2mm room for the plate by default; nut pocket 0.1mm tighter
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2026-11-01 Fit on the horn: one Shank hole setting instead of cork diameter and squeeze
    The hole the neck cork goes into, in mm (smaller = tighter). The test rings are
    the design's hole and 0.1 mm either side, named by their hole. Older files, links
    and saved designs keep their fit: the generator still reads neck_cork_diameter /
    shank_clearance, and the app turns them into the hole they made.
2026-11-08 Download menu: every file again for design files from before Shank hole
    A self-contained design file downloaded before 2026-11-01 carries the generator of
    then (neck_cork_diameter + shank_clearance), so the menu, which looked for
    shank_hole, offered only the STL. It now shows for any design made by the
    generator; only the three test rings at a given hole need the newer one. Fixes
    the missing design file download in #9.
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
